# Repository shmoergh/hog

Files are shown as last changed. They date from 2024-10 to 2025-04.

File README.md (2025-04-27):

# Hog

Fully analog two-voice monophonic synth for live performances.

hog-4

Details and user guide: [shmoergh.com](https://shmoergh.com/)

Latest revision: rev #3.

## Build

The HOG is a very fun but equally advanced electronics project. It's fully open source and we've put together a build guide for the brave ones who decide to build one. Let us know if you have questions and definitely share some pics of your builds (follow [Shmøergh on Instagram](https://www.instagram.com/shmoergh/)).

[Open build guide &rarr;](https://www.shmoergh.com/guides/hog-build-guide)

## BOMs

The HOG consists of 5 separate boards which you can find in the `boards` folder. Each board has it's own gerber files for JLCPCB PCB and Mouser BOMs in the board's `production` folders. The Core and Filter boards have SMD components too for which you can find JLCPCB assembly files (BOM and position) in the `production/jlcpcb` folder.

## Cloning

The MIDI2CV module uses [`pico-lib`](https://github.com/peterzimon/pico-lib) submodule. Make sure you clone
the repo like with its submodules:

```
git clone --recurse-submodules git@github.com:shmoergh/hog.git
```

## License

Shmoergh Hog © 2024

Hardware is licensed under [CC BY-NC 4.0](https://creativecommons.org/licenses/by-nc/4.0/)

Software is licensed under [MIT](https://opensource.org/license/mit).

Font used on PCBs: https://departuremono.com

Simulations made in [CircuitJS](https://www.falstad.com/circuit/circuitjs.html)

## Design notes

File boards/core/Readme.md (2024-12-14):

## Core board

Circuit for all core modules of HOG:

- 2x VCO
- 2x Waveshapers
- VCA
- ADSR
- 2x LFO
- Sub source
- Noise source
- Output

### Versions

**Experimental** — Some parts of the circuit contains multiple solutions, options that can be selected to build. In this version there are multiple ways to build thermal compensation for the VCOs depending on component availability (NTC based, PTS100 based); it contains a precision +/-5V circuit with output connectors that can be used on the UI board if necessary; and misc. options.

**Stable** — This is the opinionated, tested and recommended version of the core board. Compared to the experimental board:

- This board uses PTS100 for thermal compensation
- It is designed for SMD manufacturing. Note that some parts are not available at JLCPCB. We kept these THT whereever it's possible for easy build.
- +/-5V precision output is removed. Instead +/-12V resistor divider is used where needed, as approximate values were fine on the Core board.

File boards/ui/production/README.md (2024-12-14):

# Production instructions

This folder contains all the production files and a complete parts list necessary for manufacturing this board. The board contains only through-hole components. The PCB files are optimized for ordering from JLCPCB, while the through-hole components are configured for ordering from Mouser and Aliexpress.

## PCB

Upload the file `./jlcpcb/ui.zip` on [jlcpcb.com](https://www.jlcpcb.com) to order the PCB.

## Through hole components

To make ordering through hole components easy we've prepared a CSV file to generate a BOM on [mouser.com](https://www.mouser.com). Here's what you need to do:

1. Go to [https://www.mouser.com](https://www.mouser.com) and log in with your account
2. Open [BOMs](https://hu.mouser.com/OrderHistory/Boms) from the account menu
3. Click on Create New BOM
4. Upload the `./mouser/ui-mouser-bom.csv` file from this directory
5. Make sure you map the `Quantity 1` and `Mouser Product Number` columns correctly
6. Create the BOM

You can order all necessary parts at once. If a part is not available you need to find replacement components, or if you want another vendor (like Digikey) then you'll need to hunt all parts yourself.

### Switches

The switches can be ordered from Aliexpress. Check out the bom file `./aliexpress/ui-alie-bom.csv` for the links. Note that these shops are quite hectic in terms of part availability. If you can't find the switches, try searching for the part number (they're in the BOM file) in Google, Google Images, Amazon or you can even try "ON-ON toggle", "ON-ON-ON toggle" in the Chinese websites.

## Disclaimer

We are not responsible for any errors in the PCB design or the parts list. All responsibility for ordering PCBs, components, and assembly services rests solely with you.

## More important disclaimer

Have fun!

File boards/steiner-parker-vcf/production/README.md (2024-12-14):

# Production instructions

This folder contains all the production files and a complete parts list necessary for manufacturing this board. The board includes both SMD and through-hole components. The PCB and SMD production files are optimized for ordering from JLCPCB, while the through-hole components are configured for ordering from Mouser.

## PCB

Upload the file `./jlcpcb/steiner-parker-vcf.zip` on [jlcpcb.com](https://www.jlcpcb.com) to order the PCB.

## SMD assembly

On JLCPCB, select the "PCB Assembly" option. Make sure you check:

- PCBA Type: Economic
- Assembly Side: Top Side
- PCBA Qty (up to you)
- Tooling Holes: Added by Customer
- Confirm Parts Placement: Yes
- Parts Selection: By Customer

Then hit Next.

Use the `./jlcpcb/bom.csv` (BOM) and `./jlcpcb/positions.csv` (CPL — position) files respectively to order SMD assembly by JLCPCB.

> Note: the BOM file contains _all_ parts (including through holes too), so you _will_ get a warning after uploading it. You can ignore this warning and continue with ordering.

CleanShot 2024-12-14 at 11 21 11@2x

‼️ **Make sure you triplecheck the rotation of each SMD component with a dedicated pin order!**

CleanShot 2024-12-14 at 11 21 53@2x

## Through hole assembly

Well you guessed it: you'll need to solder all THT components yourself. It's fun, trust me, just make sure you don't smell the smoke from your soldering iron.

To make ordering through hole components easy we've prepared a CSV file to generate a BOM on [mouser.com](https://www.mouser.com). Here's what you need to do:

1. Go to [https://www.mouser.com](https://www.mouser.com) and log in with your account
2. Open [BOMs](https://hu.mouser.com/OrderHistory/Boms) from the account menu
3. Click on Create New BOM
4. Upload the `./mouser/steiner-parker-vcf-mouser-bom.csv` file from this directory
5. Make sure you map the `Quantity 1` and `Mouser Product Number` columns correctly
6. Create the BOM

You can order all necessary parts at once. If a part is not available you need to find replacement components, or if you want another vendor (like Digikey) then you'll need to hunt all parts yourself.

## Full BOM

The `./steiner-parker-vcf-full-bom.csv` file contains all the parts including SMD and through hole if anyone would need it.

## Disclaimer

We are not responsible for any errors in the PCB design or the parts list. All responsibility for ordering PCBs, components, and assembly services rests solely with you.

## More important disclaimer

Have fun!

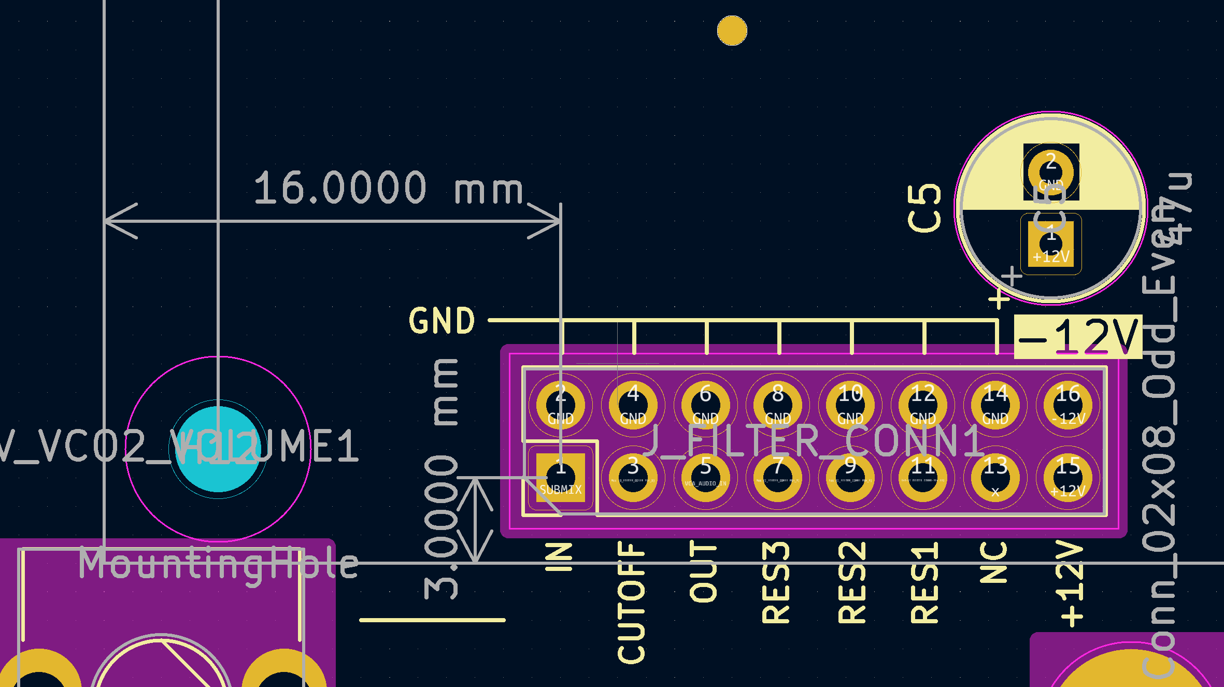
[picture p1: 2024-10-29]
boards/steiner-parker-vcf/ui-board-connection.png

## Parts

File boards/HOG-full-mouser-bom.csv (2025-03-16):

Board | Reference | Value | Footprint | Quantity | Mouser Part No | Part URL | Vendor
Core | C241 | 10u | Capacitor_THT:CP_Radial_D6.3mm_P2.50mm | 1 | 598-106RSS050M | https://mou.sr/3VxA0hV | Mouser
Core | C248 | 1u (foil or electrolite) | Capacitor_THT:C_Rect_L7.2mm_W5.5mm_P5.00mm_FKS2_FKP2_MKS2_MKP2 | 1 | 80-R82EC4100Z370K | https://mou.sr/3ZROEn2 | Mouser
Core | C251,C255 | 22n-47n (foil) | Capacitor_THT:C_Rect_L7.0mm_W2.5mm_P5.00mm | 2 | 80-R82EC1330AA50K | https://mou.sr/3BhmOHr | Mouser
Core | J201,J202,J203,J204 | Conn_02x08_Counter_Clockwise | Connector_PinHeader_2.54mm:PinHeader_2x08_P2.54mm_Vertical | 4 | 737-RS2-16-G | https://mou.sr/3OWyRwS | Mouser
Core | J214 | Conn_02x04_Counter_Clockwise | Connector_PinHeader_2.54mm:PinHeader_2x04_P2.54mm_Vertical | 1 | 737-RS2-08-G | https://mou.sr/41qYCwK | Mouser
Core | J_POWER201 | Conn_02x05_Odd_Even | Connector_PinHeader_2.54mm:PinHeader_2x05_P2.54mm_Vertical | 1 | 737-RS2-10-G | https://mou.sr/3ZuUKrQ | Mouser
Core | Q201,Q204 | 2N3906 | Package_TO_SOT_THT:TO-92L_Inline_Wide | 2 | 512-2N3906BU | https://mou.sr/3ZrOXn8 | Mouser
Core | Q203,Q206 | MMBFJ111 | PCM_Package_TO_SOT_SMD_AKL:SOT-23_Handsoldering | 2 | 512-MMBFJ111 | https://mou.sr/3Us0WP4 | Mouser
Core | Q208,Q209,Q210 | BC548C | Package_TO_SOT_THT:TO-92L_Inline_Wide | 3 | 637-BC548C | https://mou.sr/4fhkHkJ | Mouser
Core | R203,R218 | 91k | Shmoergh_Custom_Footprints:R_Axial_DIN0207_L6.3mm_D2.5mm_P7.62mm_Horizontal | 2 | 603-MFR50SFTE52-91K | https://mou.sr/3Vwa9XS | Mouser
Core | R204,R219 | 6.2k (50ppm) | Shmoergh_Custom_Footprints:R_Axial_DIN0207_L6.3mm_D2.5mm_P7.62mm_Horizontal | 2 | 603-MFR50SFTE52-6K2 | https://mou.sr/3OL65PP | Mouser
Core | R206,R221 | 4R22 (50ppm) | Shmoergh_Custom_Footprints:R_Axial_DIN0207_L6.3mm_D2.5mm_P7.62mm_Horizontal | 2 | 603-MFR50SFTE52-4R22 | https://mou.sr/49tYeQ0 | Mouser
Core | R268 | 470 | Shmoergh_Custom_Footprints:R_Axial_DIN0207_L6.3mm_D2.5mm_P7.62mm_Horizontal | 1 | 603-MFR-25FBF52-470R | https://mou.sr/3FKKllB | Mouser
Core | RV201,RV202,RV203,RV204,RV205,RV_HEADPHONE_LIM201 | 100k | Potentiometer_THT:Potentiometer_ACP_CA6-H2,5_Horizontal | 6 | 531-PT6KH104A1010PM | https://mou.sr/49zQlIS | Mouser
Core | RV_ADSR_MAX_VOLTAGE201,RV_TRI_BIAS201,RV_TRI_BIAS202 | 100k | Potentiometer_THT:Potentiometer_Bourns_3006P_Horizontal | 3 | 652-3006P-1-104-LF | https://mou.sr/4ff5W1E | Mouser
Core | RV_LINE_OUT_LVL201 | 10k | Potentiometer_THT:Potentiometer_ACP_CA6-H2,5_Horizontal | 1 | 531-PT6KH-10K | https://mou.sr/4gcYhlU | Mouser
Core | RV_SAW_BIAS201,RV_SAW_BIAS202 | 10k | Potentiometer_THT:Potentiometer_Bourns_3006P_Horizontal | 2 | 652-3006P-1-103-LF | https://mou.sr/41xh2vW | Mouser
Core | R_WIDTH201,R_WIDTH202 | 20k | Potentiometer_THT:Potentiometer_Bourns_3006P_Horizontal | 2 | 652-3006P-7-203-LF | https://mou.sr/41re1x3 | Mouser
Core | TH201,TH202 | PTS120601B100RP100 | Resistor_SMD:R_1206_3216Metric_Pad1.30x1.75mm_HandSolder | 2 | 594-PTS120601B100RP | https://mou.sr/4g7SsGi | Mouser
Core | U212 | 4002 | Package_DIP:DIP-14_W7.62mm | 1 | 595-CD4002BE | https://mou.sr/3JJTry1 | Mouser
MIDI2CV | C1,C5,C6,C10 | 22p | -- mixed values -- | 4 | 594-K220J15C0GF53L2 | https://mou.sr/3ZTXYXB | Mouser
MIDI2CV | C2 | 330n | Capacitor_THT:C_Disc_D3.0mm_W2.0mm_P2.50mm | 1 | 810-FA14X7R1H334KNU6 | https://mou.sr/4gDlMo9 | Mouser
MIDI2CV | C3,C4,C11 | 100n | Capacitor_THT:C_Disc_D3.0mm_W2.0mm_P2.50mm | 3 | 594-K103K15X7RF5TK2 | https://mou.sr/3VFZIRH | Mouser
MIDI2CV | C7 | 10u | Capacitor_THT:CP_Radial_D6.3mm_P2.50mm | 1 | 80-ESS106M035AC2EA | https://mou.sr/49DyMaU | Mouser
MIDI2CV | C8,C9 | 1u | Capacitor_THT:CP_Radial_D6.3mm_P2.50mm | 2 | 140-SG1R0M1H0407P | https://mou.sr/41BqE8O | Mouser
MIDI2CV | D1 | 1N4001 | Diode_THT:D_DO-41_SOD81_P10.16mm_Horizontal | 1 | 637-1N4001 | https://mou.sr/3DfEJyK | Mouser
MIDI2CV | D2 | 1N4148 | Diode_THT:D_DO-35_SOD27_P7.62mm_Horizontal | 1 | 512-1N4148 | https://mou.sr/3ZP7Wt3 | Mouser
MIDI2CV | JP1 | Jumper_2_Open | Connector_PinHeader_2.54mm:PinHeader_1x02_P2.54mm_Horizontal | 1 | 737-PH1RB-02-UA | https://mou.sr/3D93YT9 | Mouser
MIDI2CV | J_IN1 | Conn_01x06 | Connector_PinHeader_2.54mm:PinHeader_1x06_P2.54mm_Vertical | 1 | 737-RS1-06-G | https://mou.sr/3BuZUME | Mouser
MIDI2CV | J_OUT1,J_SWD_IO1 | Conn_01x04 | -- mixed values -- | 2 | 737-RS1-04-G | https://mou.sr/4gDjs0p | Mouser
MIDI2CV | J_SWCLKDIO1 | Conn_01x02 | Connector_PinHeader_2.54mm:PinHeader_1x02_P2.54mm_Horizontal | 1 | 737-PH1RB-02-UA | https://mou.sr/3D93YT9 | Mouser
MIDI2CV | Q_GATE_LED1 | 2N3904 | Package_TO_SOT_THT:TO-92_Inline_Wide | 1 | 637-2N3904 | https://mou.sr/4febysZ | Mouser
MIDI2CV | R1,R3 | 220 | Shmoergh_Custom_Footprints:R_Axial_DIN0207_L6.3mm_D2.5mm_P7.62mm_Horizontal | 2 | 603-MFR-25FTF52-220R | https://mou.sr/41wmEVF | Mouser
MIDI2CV | R2 | 4.7k | Shmoergh_Custom_Footprints:R_Axial_DIN0207_L6.3mm_D2.5mm_P7.62mm_Horizontal | 1 | 603-MFR-25FBF52-4K7 | https://mou.sr/4i8N07f | Mouser
MIDI2CV | R4,R12 | 47k | Shmoergh_Custom_Footprints:R_Axial_DIN0207_L6.3mm_D2.5mm_P7.62mm_Horizontal | 2 | 603-MFR-25FBF52-47K | https://mou.sr/3XWs8rz | Mouser
MIDI2CV | R5,R17 | 100k | Shmoergh_Custom_Footprints:R_Axial_DIN0207_L6.3mm_D2.5mm_P7.62mm_Horizontal | 2 | 603-MFR-25FRF52100K | https://mou.sr/4hEwI4G | Mouser
MIDI2CV | R6,R13 | 68k | Shmoergh_Custom_Footprints:R_Axial_DIN0207_L6.3mm_D2.5mm_P7.62mm_Horizontal | 2 | 603-MFR-25FBF52-68K | https://mou.sr/4gyTECt | Mouser
MIDI2CV | R7,R18 | 51k | Shmoergh_Custom_Footprints:R_Axial_DIN0207_L6.3mm_D2.5mm_P7.62mm_Horizontal | 2 | 603-MFR-25FBF52-51K | https://mou.sr/43NIOFo | Mouser
MIDI2CV | R8 | 10k | Shmoergh_Custom_Footprints:R_Axial_DIN0207_L6.3mm_D2.5mm_P7.62mm_Horizontal | 1 | 603-MFR25SFRF52-10K | https://mou.sr/3XU3MyE | Mouser
MIDI2CV | R9,R10,R14,R15,R16,R19 | 1k | Shmoergh_Custom_Footprints:R_Axial_DIN0207_L6.3mm_D2.5mm_P7.62mm_Horizontal | 6 | 603-MFR-25FBF52-1K | https://mou.sr/43MmrAb | Mouser
MIDI2CV | R11 | 470 | Shmoergh_Custom_Footprints:R_Axial_DIN0207_L6.3mm_D2.5mm_P7.62mm_Horizontal | 1 | 603-MFR-25FBF52-470R | https://mou.sr/3XTF2Xk | Mouser
MIDI2CV | U1 | LM7805_TO220 | Package_TO_SOT_THT:TO-220-3_Horizontal_TabDown | 1 | 926-LM7805CT/NOPB | https://mou.sr/4gwivXu | Mouser
MIDI2CV | U2 | 6N138 | Package_DIP:DIP-8_W7.62mm_LongPads | 1 | 859-6N138M | https://mou.sr/3VDrRsD | Mouser
MIDI2CV | U3,U6 | LM358 | Package_DIP:DIP-8_W7.62mm_LongPads | 2 | 595-LM358P | https://mou.sr/4izjQPc | Mouser
MIDI2CV | U4 | MCP4822 | Package_DIP:DIP-8_W7.62mm_LongPads | 1 | 579-MCP4822-E/P | https://mou.sr/4gecDm5 | Mouser
MIDI2CV | U5 | Pico | MCU_RaspberryPi_and_Boards:RPi_Pico_SMD_TH | 1 | 358-SC0915 | https://mou.sr/49BoTdS | Mouser
PSU | IC1 | NSD10-12D12 | NSD1012D5 | 1 | 709-NSD10-12D12 | https://mou.sr/3ZpECrS | Mouser
PSU | J1 | Conn_02x04_Odd_Even | Connector_PinSocket_2.54mm:PinSocket_2x04_P2.54mm_Vertical | 1 | 737-RS2-08-G | https://mou.sr/41qYCwK | Mouser
PSU | J2 | Conn_02x05_Odd_Even | Connector_PinSocket_2.54mm:PinSocket_2x05_P2.54mm_Vertical | 1 | 737-RS2-10-G | https://mou.sr/3ZuUKrQ | Mouser
Filter | C9,C11,C13 | 1n (Foil) | Capacitor_THT:C_Rect_L7.0mm_W2.5mm_P5.00mm | 3 | 80-R82EC1100SH50J | https://mou.sr/3ZRLX4F | Mouser
Filter | C17 | 470n (foil) | Capacitor_THT:C_Rect_L7.0mm_W3.5mm_P5.00mm | 1 | 80-R82EC1470DQ50K | https://mou.sr/4g5F5Xb | Mouser
Filter | C18 | 1u (Foil) | Capacitor_THT:C_Rect_L7.0mm_W4.5mm_P5.00mm | 1 | 80-R82EC4100Z370K | https://mou.sr/3ZROEn2 | Mouser
Filter | J1 | Eurorack Power | Connector_PinHeader_2.54mm:PinHeader_2x05_P2.54mm_Vertical | 1 | 737-RS2-10-G | https://mou.sr/3ZTZokP | Mouser
Filter | J3 | Conn_02x08_Odd_Even | Connector_PinHeader_2.54mm:PinHeader_2x08_P2.54mm_Vertical | 1 | 737-RS2-16-G | https://mou.sr/3DcrsXN | Mouser
Filter | JP_INT_EXT1 | Internal/External CV | Connector_PinSocket_2.54mm:PinSocket_1x03_P2.54mm_Vertical | 1 | 737-PH1-20-UA | https://mou.sr/4gqTRHQ | Mouser
Filter | Q1 | BC547B | Package_TO_SOT_THT:TO-92_Inline_Wide | 1 | 637-BC547B | https://mou.sr/49DWqUL | Mouser
Filter | R3 | 6.8k | Shmoergh_Custom_Footprints:R_Axial_DIN0207_L6.3mm_D2.5mm_P7.62mm_Horizontal | 1 | 603-CFR-25JB-52-6K8 | https://mou.sr/3FwCIPM | Mouser
Filter | R4 | 3.3k | Shmoergh_Custom_Footprints:R_Axial_DIN0207_L6.3mm_D2.5mm_P7.62mm_Horizontal | 1 | 603-CFR-25JB-52-3K3 | https://mou.sr/4bzT0TY | Mouser
Filter | RV_BALANCE1 | 1k | Potentiometer_THT:Potentiometer_ACP_CA6-H2,5_Horizontal | 1 | 531-PT6KH-1K | https://mou.sr/3DgNY1x | Mouser
Filter | RV_BIAS1 | 10k | Potentiometer_THT:Potentiometer_ACP_CA6-H2,5_Horizontal | 1 | 531-PT6KH-10K | https://mou.sr/49CavSt | Mouser
Filter | RV_MAX_RESO1 | 100k | Potentiometer_THT:Potentiometer_ACP_CA6-H2,5_Horizontal | 1 | 531-PT6KH104A1010PM | https://mou.sr/3OVlmh2 | Mouser
UI | C1,C2 | 100u | Capacitor_THT:CP_Radial_D6.3mm_P2.50mm | 2 | 80-ESS107M025AE2AA | https://mou.sr/3ZTs1yq | Mouser
UI | C3 | 1n | Capacitor_THT:C_Disc_D3.0mm_W2.0mm_P2.50mm | 1 | 594-K102M15X7RF53L2 | https://mou.sr/3OTl4qX | Mouser
UI | C4 | 10n | Capacitor_THT:C_Disc_D3.0mm_W2.0mm_P2.50mm | 1 | 594-K103K15X7RF5TK2 | https://mou.sr/49C1dG8 | Mouser
UI | C5 | 47u | Capacitor_THT:CP_Radial_D6.3mm_P2.50mm | 1 | 667-ECE-A1VKS470I | https://mou.sr/4iyQHDI | Mouser
UI | C7,C8,C9,C10 | 100n | Capacitor_THT:C_Disc_D3.0mm_W2.0mm_P2.50mm | 4 | 594-K103K15X7RF5TK2 | https://mou.sr/3VFZIRH | Mouser
UI | C12 | 470n | Capacitor_THT:C_Disc_D3.0mm_W2.0mm_P2.50mm | 1 | 80-C315C474K5R | https://mou.sr/4ggiw21 | Mouser
UI | D1,D3,D_ON_OFF1 | LED Blue | LED_THT:LED_D5.0mm | 3 | 859-LTL-1CHG | https://mou.sr/3OXMWKk | Mouser
UI | D2 | 8.2V | Diode_THT:D_DO-41_SOD81_P7.62mm_Horizontal | 1 | 625-BZX85C8V2 | https://mou.sr/3DeplTn | Mouser
UI | J1,J2,J3,J4 | Conn_02x08_Counter_Clockwise | Connector_PinHeader_2.54mm:PinHeader_2x08_P2.54mm_Vertical | 4 | 649-1012938191601BLF | https://mou.sr/3ZS3vh3 | Mouser
UI | J5 | Conn_02x04_Counter_Clockwise | Connector_PinHeader_2.54mm:PinHeader_2x04_P2.54mm_Vertical | 1 | 737-PH2-08-UA | https://mou.sr/4gxLnib | Mouser
UI | J6 | Barrel_Jack_Switch | Connector_BarrelJack:BarrelJack_Wuerth_6941xx301002 | 1 | 710-694106301002 | https://mou.sr/4a9ckVQ | Mouser
UI | J8 | Conn_01x06 | Connector_PinHeader_2.54mm:PinHeader_1x06_P2.54mm_Vertical | 1 | 737-PH1-20-UA | https://mou.sr/4gqTRHQ | Mouser
UI | J9 | Conn_02x04_Odd_Even | Connector_PinHeader_2.54mm:PinHeader_2x04_P2.54mm_Vertical | 1 | 737-PH2-08-UA | https://mou.sr/4gxLnib | Mouser
UI | J_EXT_CUTOFF1,J_GATE1,J_HEADPHONES1,J_MIDI_IN1,J_PITCH1,J_VCO2_PITCH1 | SJ1-3554NG | Shmoergh_Custom_Footprints:CUI_SJ1-3554NG | 6 | 490-SJ1-3554NG | https://mou.sr/3Qs21VB | Mouser
UI | J_FILTER_CONN1 | Conn_02x08_Odd_Even | Connector_PinHeader_2.54mm:PinHeader_2x08_P2.54mm_Vertical | 1 | 649-1012938191601BLF | https://mou.sr/3ZS3vh3 | Mouser
UI | J_MAIN_POWER1,J_POWER1 | Conn_02x05_Odd_Even | Connector_PinHeader_2.54mm:PinHeader_2x05_P2.54mm_Vertical | 2 | 737-PH2-10-UA | https://mou.sr/3D13TAT | Mouser
UI | Q1,Q2 | 2N3904 | Package_TO_SOT_THT:TO-92L_Inline_Wide | 2 | 637-2N3904 | https://mou.sr/4febysZ | Mouser
UI | R1 | 1k | Shmoergh_Custom_Footprints:R_Axial_DIN0207_L6.3mm_D2.5mm_P7.62mm_Horizontal | 1 | 603-MFR-25FBF52-1K | https://mou.sr/43MmrAb | Mouser
UI | R2,R44,R45 | 200k | Shmoergh_Custom_Footprints:R_Axial_DIN0207_L6.3mm_D2.5mm_P7.62mm_Horizontal | 3 | 603-MFR-25FTF52-200K | https://mou.sr/49BK9jG | Mouser
UI | R3,R4,R5,R6,R7,R14,R15,R16,R17 | 10k (0.1%) | Shmoergh_Custom_Footprints:R_Axial_DIN0207_L6.3mm_D2.5mm_P7.62mm_Horizontal | 9 | 660-MF1/4CCT52R1002B | https://mou.sr/4fj3JT3 | Mouser
UI | R8 | 150k | Shmoergh_Custom_Footprints:R_Axial_DIN0207_L6.3mm_D2.5mm_P7.62mm_Horizontal | 1 | 603-MFR-25FBF52-150K | https://mou.sr/3DLvBCw | Mouser
UI | R9,R10,R26,R30,R38,R40,R49 | 100k | Shmoergh_Custom_Footprints:R_Axial_DIN0207_L6.3mm_D2.5mm_P7.62mm_Horizontal | 7 | 603-MFR-25FRF52100K | https://mou.sr/4hEwI4G | Mouser
UI | R11,R12,R13,R19,R20,R21,R22,R25,R31,R32,R33 | 100k (1%) | Shmoergh_Custom_Footprints:R_Axial_DIN0207_L6.3mm_D2.5mm_P7.62mm_Horizontal | 11 | 603-MFR-25FRF52100K | https://mou.sr/4hEwI4G | Mouser
UI | R18,R23,R24,R39 | 82k | Shmoergh_Custom_Footprints:R_Axial_DIN0207_L6.3mm_D2.5mm_P7.62mm_Horizontal | 4 | 603-MFR-25FBF52-82K | https://mou.sr/4bFupx1 | Mouser
UI | R27,R28,R35,R36,R43,R50,R51 | 10k | Shmoergh_Custom_Footprints:R_Axial_DIN0207_L6.3mm_D2.5mm_P7.62mm_Horizontal | 7 | 603-MFR25SFRF52-10K | https://mou.sr/3XU3MyE | Mouser
UI | R29 | 330k | Shmoergh_Custom_Footprints:R_Axial_DIN0207_L6.3mm_D2.5mm_P7.62mm_Horizontal | 1 | 603-MFR-25FRF52-330K | https://mou.sr/3FzGuYE | Mouser
UI | R34 | 2k | Shmoergh_Custom_Footprints:R_Axial_DIN0207_L6.3mm_D2.5mm_P7.62mm_Horizontal | 1 | 603-MFR-25FTF52-2K | https://mou.sr/425kXjj | Mouser
UI | R37,R41 | 20k | Shmoergh_Custom_Footprints:R_Axial_DIN0207_L6.3mm_D2.5mm_P7.62mm_Horizontal | 2 | 603-MFR-25FRF5220K | https://mou.sr/4bBnUeQ | Mouser
UI | R42 | 4.7k | Shmoergh_Custom_Footprints:R_Axial_DIN0207_L6.3mm_D2.5mm_P7.62mm_Horizontal | 1 | 603-MFR-25FBF52-4K7 | https://mou.sr/4i8N07f | Mouser
UI | R46,R47 | 220 | Shmoergh_Custom_Footprints:R_Axial_DIN0207_L6.3mm_D2.5mm_P7.62mm_Horizontal | 2 | 603-MFR-25FTE52-220R | https://mou.sr/428sz4x | Mouser
UI | R48 | 47k | Shmoergh_Custom_Footprints:R_Axial_DIN0207_L6.3mm_D2.5mm_P7.62mm_Horizontal | 1 | 603-MFR-25FTE52-47K | https://mou.sr/4iUy6Bg | Mouser
UI | RV1,RV2 | 50k prec. | Potentiometer_THT:Potentiometer_Bourns_3006P_Horizontal | 2 | 652-3006P-1-503-LF | https://mou.sr/3ZEVzhM | Mouser
UI | RV_ATTACK_LONG1,RV_DECAY_SHORT1,RV_DIRTY_AMP1,RV_EXT_CUTOFF_GAIN1,RV_GLIDE_AMNT1,RV_NARROW_WIDTH1,RV_PLAYGROUND_HALF1,RV_RELEASE_MIN1,RV_RELEASE_SHORT1,RV_SUSTAIN_LVL1,RV_SYNC_VIBRATO_DAMP1,RV_TRACKING_LVL1,RV_VCA_PLYGND_BIAS1 | 100k | Potentiometer_THT:Potentiometer_Runtron_RM-065_Vertical | 13 | 652-3306F-1-104 | https://mou.sr/3OVBYFf | Mouser
UI | RV_ATTACK_SHORT1 | 10k | Potentiometer_THT:Potentiometer_Runtron_RM-065_Vertical | 1 | 652-3306F-1-103 | https://mou.sr/41GreC6 | Mouser
UI | RV_CUTOFF1,RV_VCO2_TUNER1 | 100k | Shmoergh_Custom_Footprints:Potentiometer_Bourns_Single-PTV09A | 2 | 652-PTV09A4025FB104 | https://mou.sr/3Us6dpJ | Mouser
UI | RV_FINE_TUNE1 | 10k | Shmoergh_Custom_Footprints:Potentiometer_Bourns_PTD901-2015_Single_Horizontal | 1 | PTD901-1015K-B103 | https://mou.sr/4aB7CRn | Mouser
UI | RV_LFO1_AMOUNT1,RV_LFO1_SPEED1,RV_LFO2_AMOUNT1,RV_LFO2_SPEED1,RV_NOISE_VOLUME1,RV_VCO2_VOLUME1 | A100k | Shmoergh_Custom_Footprints:Potentiometer_Bourns_Single-PTV09A | 6 | 652-PTV09A-4025UA104 | https://mou.sr/44vDepN | Mouser
UI | RV_MAIN_VCO_5V1 | 10k | Potentiometer_THT:Potentiometer_Bourns_3006P_Horizontal | 1 | 652-3006P-1-103-LF | https://mou.sr/41xh2vW | Mouser
UI | RV_PWM_LEVEL1,RV_SUSTAIN_MAX1 | 200k | Potentiometer_THT:Potentiometer_Runtron_RM-065_Vertical | 2 | 652-3306F-1-204 | https://mou.sr/3P2IKcd | Mouser
UI | RV_RESO_DIRTY1 | 50k | Shmoergh_Custom_Footprints:Potentiometer_Bourns_Dual-PTV112-4 | 1 | 652-PTV112-4425AB503 | https://mou.sr/3UKAAJn | Mouser
UI | RV_RINGTIME1 | 500k | Shmoergh_Custom_Footprints:Potentiometer_Bourns_Dual-PTV112-4 | 1 | 652-PTV1124420AA504 | https://mou.sr/47iqFh2 | Mouser
UI | RV_VOLUME1 | A10k | Shmoergh_Custom_Footprints:Potentiometer_Bourns_Single-PTV09A | 1 | 652-PTV09A4025FA103 | https://mou.sr/4bCOV0e | Mouser
UI | S1 | PB400EEQR1BLK | Shmoergh_Custom_Footprints:SW_PB400EEQR1BLK | 1 | 612-PB400EEQR1BLK | https://mou.sr/3TDv9tV | Mouser
UI | SW_OCTAVE1,SW_WAVESHAPE1 | SW_Rotary2x5 | Shmoergh_Custom_Footprints:SW_SR2512F-2x5-rotary | 2 | 105-SR2512F-25NS | https://mou.sr/49HHdSv | Mouser
UI | SW_PLAYGROUND1 | SW_Rotary3x4 | Shmoergh_Custom_Footprints:SW_SR2512F-3x4-rotary | 1 | 105-SR2512F-34NS | https://mou.sr/3wb0uwA | Mouser
UI | U1,U2 | TL072 | PCM_Package_DIP_AKL:DIP-8_W7.62mm_Socket_LongPads | 2 | 595-TL072IP | https://mou.sr/4g5XjI5 | Mouser
UI | U_5VREF1 | LM336Z5 | Package_TO_SOT_THT:TO-92L_Inline_Wide | 1 | 926-LM336Z-50/NOPB | https://mou.sr/3y3TEcP | Mouser
UI | U_ADSR_SW_IC1 | CD4053B | Package_DIP:DIP-16_W7.62mm | 1 | 595-CD4053BE | https://mou.sr/4a7avII | Mouser

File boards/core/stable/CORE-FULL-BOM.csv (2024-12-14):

Reference | Value | Datasheet | Footprint | Qty | DNP | LCSC | Part No. | Part URL | Vendor
C201,C202,C203,C204,C205,C206,C211,C212,C213,C214,C215,C216,C221,C222,C223,C224,C229,C230,C231,C232,C233,C234,C237,C238,C239,C242,C243,C244,C245,C246,C247,C249,C250,C253,C254,C257,C258,C259,C262,C263,C265,C266,C267,C268,C269,C270,C278,C279 | 100n | ~ | Capacitor_SMD:C_0603_1608Metric | 48 |  | C14663 |  |  | JLCPCB
C208,C218,C276 | 100p | ~ | Capacitor_SMD:C_0603_1608Metric | 3 |  | C14858 |  |  | JLCPCB
C210,C220 | 22p | ~ | Capacitor_SMD:C_0603_1608Metric | 2 |  | C1653 |  |  | JLCPCB
C225,C226,C227,C275 | 22uF | ~ | Capacitor_SMD:CP_Elec_6.3x5.4 | 4 |  | C2836438 |  |  | JLCPCB
C236,C272 | 33p | ~ | Capacitor_SMD:C_0603_1608Metric | 2 |  | C1663 |  |  | JLCPCB
C240 | 10n | ~ | Capacitor_SMD:C_0603_1608Metric | 1 |  | C57112 |  |  | JLCPCB
C241 | 10u | ~ | Capacitor_THT:CP_Radial_D6.3mm_P2.50mm | 1 |  |  | 598-106RSS050M | https://mou.sr/3VxA0hV | Mouser
C248 | 1u (foil or electrolite) | ~ | Capacitor_THT:C_Rect_L7.2mm_W5.5mm_P5.00mm_FKS2_FKP2_MKS2_MKP2 | 1 |  |  | 80-R82EC4100Z370K | https://mou.sr/3ZROEn2 | Mouser
C251,C255 | 22n-47n (foil) | ~ | Capacitor_THT:C_Rect_L7.0mm_W2.5mm_P5.00mm | 2 |  |  | 80-R82EC1330AA50K | https://mou.sr/3BhmOHr | Mouser
C252,C256,C280,C281 | 47u | ~ | Capacitor_SMD:CP_Elec_6.3x5.4 | 4 |  | C3344 |  |  | JLCPCB
C260,C261 | 100u | ~ | Capacitor_SMD:CP_Elec_6.3x7.7 | 2 |  | C2836437 |  |  | JLCPCB
C273,C274,C282,C283,C284,C285 | 47p | ~ | Capacitor_SMD:C_0603_1608Metric | 6 |  | C1671 |  |  | JLCPCB
C277 | 1u | ~ | Capacitor_SMD:C_0603_1608Metric_Pad1.08x0.95mm_HandSolder | 1 |  | C15849 |  |  | JLCPCB
D203,D204,D207,D212,D213,D216,D217 | 1N4148 | ~ | Diode_SMD:D_SOD-123 | 7 |  | C81598 |  |  | JLCPCB
J201,J202,J203,J204 | Conn_02x08_Counter_Clockwise | ~ | Connector_PinHeader_2.54mm:PinHeader_2x08_P2.54mm_Vertical | 4 |  |  | 737-RS2-16-G | https://mou.sr/3OWyRwS | Mouser
J214 | Conn_02x04_Counter_Clockwise | ~ | Connector_PinHeader_2.54mm:PinHeader_2x04_P2.54mm_Vertical | 1 |  |  | 737-RS2-08-G | https://mou.sr/41qYCwK | Mouser
J_POWER201 | Conn_02x05_Odd_Even | ~ | Connector_PinHeader_2.54mm:PinHeader_2x05_P2.54mm_Vertical | 1 |  |  | 737-RS2-10-G | https://mou.sr/3ZuUKrQ | Mouser
Q201,Q204 | 2N3906 | https://www.tme.eu/Document/1d69ece8147fa5a64114d103f531c790/2N3906BU.pdf | Package_TO_SOT_THT:TO-92L_Inline_Wide | 2 |  |  | 512-2N3906BU | https://mou.sr/3ZrOXn8 | Mouser
Q202,Q205 | BC847BS | https://www.tme.eu/Document/82748fbc26f250e671ae2786c3be5a04/BC847BS.115.pdf | Package_TO_SOT_SMD:SOT-363_SC-70-6_Handsoldering | 2 |  | C5380687 |  |  | JLCPCB
Q203,Q206 | MMBFJ111 | https://www.tme.eu/Document/2ab8d7a6d6d8a209f9d7deeb52763e9f/J111.pdf | PCM_Package_TO_SOT_SMD_AKL:SOT-23_Handsoldering | 2 |  |  | 512-MMBFJ111 | https://mou.sr/3Us0WP4 | Mouser
Q207 | BC847BS | https://www.tme.eu/Document/82748fbc26f250e671ae2786c3be5a04/BC847BS.115.pdf | Package_TO_SOT_SMD:SOT-363_SC-70-6 | 1 |  | C5380687 |  |  | JLCPCB
Q208,Q209,Q210 | BC548C | https://www.onsemi.com/pub/Collateral/BC550-D.pdf | Package_TO_SOT_THT:TO-92L_Inline_Wide | 3 |  |  | 637-BC548C | https://mou.sr/4fhkHkJ | Mouser
Q212,Q213,Q214 | MMBT5551 | https://datasheet.lcsc.com/lcsc/2304140030_Jiangsu-Changjing-Electronics-Technology-Co---Ltd--MMBT5551_C2145.pdf | Package_TO_SOT_SMD:SOT-23 | 3 |  | C2145 |  |  | JLCPCB
R201,R213,R216,R228,R232,R235,R237,R242,R243,R244,R246,R247,R250,R252,R253,R254,R255,R262,R263,R264,R278,R279,R280,R281,R282,R283,R284,R285,R286,R287,R301,R304,R306,R307,R308,R309,R316,R317,R318,R319,R326,R327,R328,R329,R335,R336,R337,R338,R339,R340 | 100k | ~ | Resistor_SMD:R_0603_1608Metric | 50 |  | C25803 |  |  | JLCPCB
R202,R212,R217,R227 | 150k | ~ | Resistor_SMD:R_0603_1608Metric | 4 |  | C22807 |  |  | JLCPCB
R203,R218 | 91k | ~ | Shmoergh_Custom_Footprints:R_Axial_DIN0207_L6.3mm_D2.5mm_P7.62mm_Horizontal | 2 |  |  | 603-MFR50SFTE52-91K | https://mou.sr/3Vwa9XS | Mouser
R204,R219 | 6.2k (50ppm) | ~ | Shmoergh_Custom_Footprints:R_Axial_DIN0207_L6.3mm_D2.5mm_P7.62mm_Horizontal | 2 |  |  | 603-MFR50SFTE52-6K2 | https://mou.sr/3OL65PP | Mouser
R205,R208,R220,R223,R322,R323 | 1M | ~ | Resistor_SMD:R_0603_1608Metric | 6 |  | C22935 |  |  | JLCPCB
R206,R221 | 4R22 (50ppm) | ~ | Shmoergh_Custom_Footprints:R_Axial_DIN0207_L6.3mm_D2.5mm_P7.62mm_Horizontal | 2 |  |  | 603-MFR50SFTE52-4R22 | https://mou.sr/49tYeQ0 | Mouser
R207,R209,R222,R224 | 1.5k | ~ | Resistor_SMD:R_0603_1608Metric | 4 |  | C22843 |  |  | JLCPCB
R210,R225 | 510 | ~ | Resistor_SMD:R_0603_1608Metric | 2 |  | C23193 |  |  | JLCPCB
R211,R226 | 22k | ~ | Resistor_SMD:R_0603_1608Metric | 2 |  | C31850 |  |  | JLCPCB
R214,R229 | 330k | ~ | Resistor_SMD:R_0603_1608Metric | 2 |  | C23137 |  |  | JLCPCB
R215,R230,R258,R297,R312 | 2.2k | ~ | Resistor_SMD:R_0603_1608Metric | 5 |  | C4190 |  |  | JLCPCB
R231 | 4.7k | ~ | Resistor_SMD:R_0603_1608Metric | 1 |  | C23162 |  |  | JLCPCB
R233 | 220 | ~ | Resistor_SMD:R_0603_1608Metric | 1 |  | C22962 |  |  | JLCPCB
R234,R245 | 33k | ~ | Resistor_SMD:R_0603_1608Metric | 2 |  | C4216 |  |  | JLCPCB
R236,R238,R239,R266,R288,R289,R324,R325 | 10k | ~ | Resistor_SMD:R_0603_1608Metric | 8 |  | C25804 |  |  | JLCPCB
R240,R241,R296 | 470k | ~ | Resistor_SMD:R_0603_1608Metric | 3 |  | C23178 |  |  | JLCPCB
R248,R249,R302,R303 | 15k | ~ | Resistor_SMD:R_0603_1608Metric | 4 |  | C22809 |  |  | JLCPCB
R251,R305 | 27k | ~ | Resistor_SMD:R_0603_1608Metric | 2 |  | C22967 |  |  | JLCPCB
R256,R259,R310,R313,R320 | 220k | ~ | Resistor_SMD:R_0603_1608Metric | 5 |  | C22961 |  |  | JLCPCB
R257,R267,R290,R291,R292,R293,R311,R321,R330,R331,R332,R333,R334 | 47k | ~ | Resistor_SMD:R_0603_1608Metric | 13 |  | C25819 |  |  | JLCPCB
R260,R314 | 2.2M | ~ | Resistor_SMD:R_0603_1608Metric | 2 |  | C22938 |  |  | JLCPCB
R261,R300,R315 | 240k | ~ | Resistor_SMD:R_0603_1608Metric | 3 |  | -- mixed values -- |  |  | JLCPCB
R265 | 75k | ~ | Resistor_SMD:R_0603_1608Metric | 1 |  | C23242 |  |  | JLCPCB
R268 | 470 | ~ | Shmoergh_Custom_Footprints:R_Axial_DIN0207_L6.3mm_D2.5mm_P7.62mm_Horizontal | 1 |  |  | 303-CFR0W4J0471B00 | https://mou.sr/49DiyPd | Mouser
R269,R272,R277,R294,R295 | 1k | ~ | Resistor_SMD:R_0603_1608Metric | 5 |  | C21190 |  |  | JLCPCB
R270 | 100k | ~ | Resistor_SMD:R_0603_1608Metric_Pad0.98x0.95mm_HandSolder | 1 |  | C25803 |  |  | JLCPCB
R271 | 150 | ~ | Resistor_SMD:R_0603_1608Metric | 1 |  | C22808 |  |  | JLCPCB
R273,R274 | 100 | ~ | Resistor_SMD:R_0603_1608Metric | 2 |  | C22775 |  |  | JLCPCB
R298 | 3.3M | ~ | Resistor_SMD:R_0603_1608Metric | 1 |  | C141659 |  |  | JLCPCB
RV201,RV202,RV203,RV204,RV205,RV_HEADPHONE_LIM201 | 100k | ~ | Potentiometer_THT:Potentiometer_ACP_CA6-H2,5_Horizontal | 6 |  |  | 531-PT6KH104A1010PM | https://mou.sr/49zQlIS | Mouser
RV_ADSR_MAX_VOLTAGE201,RV_TRI_BIAS201,RV_TRI_BIAS202 | 100k | ~ | Potentiometer_THT:Potentiometer_Bourns_3006P_Horizontal | 3 |  |  | 652-3006P-1-104-LF | https://mou.sr/4ff5W1E | Mouser
RV_LINE_OUT_LVL201 | 10k | ~ | Potentiometer_THT:Potentiometer_ACP_CA6-H2,5_Horizontal | 1 |  |  | 531-PT6KH-10K | https://mou.sr/4gcYhlU | Mouser
RV_SAW_BIAS201,RV_SAW_BIAS202 | 10k | ~ | Potentiometer_THT:Potentiometer_Bourns_3006P_Horizontal | 2 |  |  | 652-3006P-1-103-LF | https://mou.sr/41xh2vW | Mouser
R_WIDTH201,R_WIDTH202 | 20k | ~ | Potentiometer_THT:Potentiometer_Bourns_3006P_Horizontal | 2 |  |  | 652-3006P-7-203-LF | https://mou.sr/41re1x3 | Mouser
TH201,TH202 | PTS120601B100RP100 | ~ | Resistor_SMD:R_1206_3216Metric_Pad1.30x1.75mm_HandSolder | 2 |  |  | 594-PTS120601B100RP | https://mou.sr/4g7SsGi | Mouser
U201,U202,U204,U205,U207,U208,U209,U210,U211,U214,U217,U218,U219,U220,U221,U222,U223,U225,U226,U227 | TL072 | http://www.ti.com/lit/ds/symlink/tl071.pdf | Package_SO:SOIC-8_3.9x4.9mm_P1.27mm | 20 |  | C6961 |  |  | JLCPCB
U203,U206 | LM311 | https://www.st.com/resource/en/datasheet/lm311.pdf | Package_SO:SOIC-8_3.9x4.9mm_P1.27mm | 2 |  | C12597 |  |  | JLCPCB
U212 | 4002 | http://www.intersil.com/content/dam/Intersil/documents/cd40/cd4000bms-01bms-02bms-25bms.pdf | Package_DIP:DIP-14_W7.62mm | 1 |  |  | 595-CD4002BE | https://mou.sr/3JJTry1 | Mouser
U213 | LM358 | http://www.ti.com/lit/ds/symlink/lm2904-n.pdf | Package_SO:SOIC-8_3.9x4.9mm_P1.27mm | 1 |  | C7950 |  |  | JLCPCB
U215 | CD4053B | http://www.ti.com/lit/ds/symlink/cd4052b.pdf | Package_SO:SOIC-16_3.9x9.9mm_P1.27mm | 1 |  | C6742 |  |  | JLCPCB
U216 | NE5532 | http://www.ti.com/lit/ds/symlink/ne5532.pdf | Package_SO:SOIC-8_3.9x4.9mm_P1.27mm | 1 |  | C7426 |  |  | JLCPCB
U228 | CD4040BM96 | http://www.intersil.com/content/dam/Intersil/documents/cd40/cd4020bms-24bms-40bms.pdf | Package_SO:SOIC-16_3.9x9.9mm_P1.27mm | 1 |  | C353974 |  |  | JLCPCB

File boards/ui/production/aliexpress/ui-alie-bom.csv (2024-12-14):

Reference | Value | Datasheet | Footprint | Qty | DNP | Part No. | Part URL | Vendor
SW_AUTO_WAH_AB1,SW_GATE_ADSR1,SW_NOISE_SUB1,SW_PLAYGROUND_LVL1,SW_VCO2_OCT_DIR1,SW_VCO2_WAVE1,SW_VIBRATO_AB1 | SW_DP3T | ~ | Shmoergh_Custom_Footprints:DP3T Korg Style Switch | 7 |  | TS23-E02 | https://www.aliexpress.com/item/32958319752.html | Daier
SW_GLIDE1,SW_HOLD1,SW_RING1,SW_SOFT1,SW_TRACK1,SW_VCO2_OCT_AMNT1,SW_VCO2_ON1 | SW_DPDT_x2 | ~ | Shmoergh_Custom_Footprints:DPDT Korg Style Switch | 7 |  | TS-22E01AT15 | https://www.aliexpress.com/item/32955400123.html | Daier

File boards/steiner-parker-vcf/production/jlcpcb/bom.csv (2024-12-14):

Designator | Footprint | Quantity | Value | LCSC Part #
C1, C2, C22, C23 | CP_Elec_6.3x7.7 | 4 | 100u | C2836437
C10 | CP_Elec_4x5.4 | 1 | 2.2u | C43242
C11, C13, C9 | C_Rect_L7.0mm_W2.5mm_P5.00mm | 3 | 1n (Foil)
C14, C16, C20, C21, C3, C4, C6, C7 | 0603 | 8 | 100n | C14663
C17 | C_Rect_L7.0mm_W3.5mm_P5.00mm | 1 | 470n (foil)
C18 | C_Rect_L7.0mm_W4.5mm_P5.00mm | 1 | 1u (Foil)
C19 | CP_Elec_4x5.4 | 1 | 10u | C3343
C8 | 0603 | 1 | 10n | C57112
D1, D10, D2, D3, D4, D5, D6, D7, D8, D9 | D_SOD-123 | 10 | 1N4148 | C81598
J1 | PinHeader_2x05_P2.54mm_Vertical | 1 | Eurorack Power
J3 | PinHeader_2x08_P2.54mm_Vertical | 1 | Conn_02x08_Odd_Even
JP_INT_EXT1 | PinSocket_1x03_P2.54mm_Vertical | 1 | Internal/External CV
Q1 | TO-92_Inline_Wide | 1 | BC547B
R10 | 0603 | 1 | 56k | C23206
R11, R32, R5 | 0603 | 3 | 10k | C25804
R12, R28 | 0603 | 2 | 47k | C25819
R13 | 0603 | 1 | 200k | C25811
R14 | 0603 | 1 | 180k | C3016400
R15 | 0603 | 1 | 2.7k | C13167
R16, R24 | 0603 | 2 | 1.5k (1%) | C22843
R17 | 0603 | 1 | 2.2k | C4190
R18 | 0603 | 1 | 100 | C22775
R19 | 0603 | 1 | 390 | C23151
R20, R21, R25, R35 | 0603 | 4 | 1k | C21190
R22 | 0603 | 1 | 3.9k | C23018
R23 | 0603 | 1 | 200 | C8218
R26, R29 | 0603 | 2 | 1M | C22935
R27 | 0603 | 1 | 22k | C31850
R3 | R_Axial_DIN0207_L6.3mm_D2.5mm_P7.62mm_Horizontal | 1 | 6.8k
R31, R9 | 0603 | 2 | 220k | C22961
R33, R34, R6 | 0603 | 3 | 100k | C25803
R4 | R_Axial_DIN0207_L6.3mm_D2.5mm_P7.62mm_Horizontal | 1 | 3.3k
RV_BALANCE1 | Potentiometer_ACP_CA6-H2,5_Horizontal | 1 | 1k
RV_BIAS1 | Potentiometer_ACP_CA6-H2,5_Horizontal | 1 | 10k
RV_MAX_RESO1 | Potentiometer_ACP_CA6-H2,5_Horizontal | 1 | 100k
U1, U2, U3 | SOIC-8_3.9x4.9mm_P1.27mm | 3 | TL072 | C6961

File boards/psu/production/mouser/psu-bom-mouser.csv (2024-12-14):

Reference | Value | Footprint | Quantity 1 | DNP | Vendor | Mouser Part Number | Part URL
IC1 | NSD10-12D12 | NSD1012D5 | 1 |  | Mouser | 709-NSD10-12D12 | https://mou.sr/3ZpECrS
J1 | Conn_02x04_Odd_Even | Connector_PinSocket_2.54mm:PinSocket_2x04_P2.54mm_Vertical | 1 |  | Mouser | 737-RS2-08-G | https://mou.sr/41qYCwK
J2 | Conn_02x05_Odd_Even | Connector_PinSocket_2.54mm:PinSocket_2x05_P2.54mm_Vertical | 1 |  | Mouser | 737-RS2-10-G | https://mou.sr/3ZuUKrQ

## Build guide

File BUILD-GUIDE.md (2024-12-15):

# Build guide

[Open build guide &rarr;](https://www.shmoergh.com/hog-build-guide)

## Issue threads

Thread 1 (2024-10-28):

Build guide request

machinehistories, 2024-10-28:
This is a terrific looking device and I'd be interested to try and build one. I see the guide on the synth features but do you have a build guide. Is there one already available and if not is there one in the works. Keep up the good work. Thanks

peterzimon, 2024-10-30:
@machinehistories Thank you! I'm working on one, will ping you when it's available 😎

machinehistories, 2024-11-05:
thanks appreciate it

peterzimon, 2024-12-15:
@machinehistories I've added BOMs and production files to all boards.

Also I've written a build guide here:

[https://www.shmoergh.com/hog-build-guide/](https://www.shmoergh.com/hog-build-guide/)

Hope it's useful ✌️

machinehistories, 2024-12-16:
thanks that's terrific

On Sun, Dec 15, 2024 at 5:15 AM Peter Zimon ***@***.***>
wrote:

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

Closed 2024-12-15.

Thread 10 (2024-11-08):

Add THT footprint to J111 in VCOs

peterzimon, 2024-11-08:
Having a dual footprint for the J111 prepares the circuit for potential SMD component shortage

Closed 2024-11-23.

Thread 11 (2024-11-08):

Update filter trimmer footprints to use horizontal ones

peterzimon, 2024-11-08:
At the moment it's vertical which makes it impossible to fine tune.

shmoergh, 2024-11-23:
Done with https://github.com/shmoergh/hog/issues/24

Closed 2024-11-23.

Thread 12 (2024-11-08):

Research and replace non-precision trimmers to SMD ones

peterzimon, 2024-11-08:
- [x] Research parts
- [ ] Replace 'em

shmoergh, 2024-11-23:
JLCPCB parts
100kΩ — C719186
10kΩ — C911365
50kΩ — C145161

shmoergh, 2024-11-23:
Changed plan: the available SMD components can only be set from the top (vertically) so the UI board would cover the trimpots making it non-accessible.

Closed 2024-11-23.

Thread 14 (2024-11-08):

Fix PWM input of VCO1

peterzimon, 2024-11-08:
PWM input of VCO1 should be directly connected to the output of VCO2, not to the output of the amount knob to make PWM value independent.

shmoergh, 2024-11-23:
Solved with https://github.com/shmoergh/hog/issues/24

Closed 2024-11-23.

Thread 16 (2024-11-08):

Add safety OR circuit to MIDI2CV power input

peterzimon, 2024-11-08:
Currently he USB power of the Pico on the MIDI2CV board is directly connested to the 5V output of the regulator which can cause damage in the connected computer if the synth is turned on. The circuit should be updated so that only the synth's own power supplies are used in this case.

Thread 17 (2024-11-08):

Create gerber files for each board

peterzimon, 2024-11-08:
Prepare all boards to be easy to order from JLCPCB.

- [x] Core board
- [x] UI board
- [x] PSU board
- [x] MIDI board
- [x] Filter board

Closed 2024-12-14.

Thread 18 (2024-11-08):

Add paraphonic mode via MIDI

peterzimon, 2024-11-08:
Paraphonic mode is only supported via CV input at the moment. It should work with MIDI too but it's not obvious how to implement it.

### Problem

At the moment the pitch of VCO 2 is normalized to the _glided_ pitch of VCO 1, and VCO 1 pitch is normalized to MIDI pitch. This makes sure that the pitch of the two VCOs are always the same. How to update this to allow two MIDI pitches set the two VCOs separately.

peterzimon, 2024-12-09:
The solution is not obvious, we'll opt for making MIDI work properly in monophonic mode (single CV from MIDI + glide on both voices) and keep CV-only paraphonic mode.

Closed 2024-12-09.

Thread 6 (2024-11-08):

Reposition VCO tuning trimpots

peterzimon, 2024-11-08:
At the moment, PSU board is in the way which makes it very hard to tune. Alternatively top-screw trimpots and holes on the UI board could work

peterzimon, 2024-11-30:
Closed with https://github.com/shmoergh/hog/commit/a9f9715e1053f44825b6762ae9e018dc59ed68b0

Closed 2024-11-30.

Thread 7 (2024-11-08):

Separate VCO thermal compensation options

peterzimon, 2024-11-08:
Currently the VCO circuit is designes with two potential ways to compensate thermal drifts to prepare for component shortage. Create two alternative circuits that only uses each, so it's simpler to order.

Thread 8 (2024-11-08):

Simplify VCA

peterzimon, 2024-11-08:
The CV rejection trimpot at the connection of the diff-pair collectors is almost never needed, since a single package transistor pair is used, and the drift voltage is minimal. The trimpot can be removed.

Closed 2024-11-23.

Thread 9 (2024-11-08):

Simplify Core/Mixer

peterzimon, 2024-11-08:
Use SMD resistor in the feedback loop of the first inverting amp. It's been THT for experimentation purposes

Closed 2024-11-23.

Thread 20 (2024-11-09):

Reconnect MIDI2CV pitch outputs

peterzimon, 2024-11-09:
Currently the "Fat pitch" jack input is defaulted to the normal CV (pitch) input. This doesn't allow to use the MIDI2CV converter to control the pitch of the "Fat" (2nd) voice with the same technique, ie. it's not possible to default the "Fat" pitch to both the output of the MIDI2CV converter's DAC and the normal CV.

Instead, the DAC outputs (pitch 1 and 2) from the MIDI2CV converter should be connected to the CV input of the two voices, respectively. This would decouple the MIDI CV from the CV jacks.

peterzimon, 2024-11-09:
Will be done via #18

Closed 2024-11-09.

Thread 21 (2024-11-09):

Use PWM for modwheel

peterzimon, 2024-11-09:
Currently one of the DAC output is used for the modwheel CV. Instead use PWM to set the voltage of Gate B so that the DAC output can be used to set the pitch of voise 2 ("Fat")

peterzimon, 2024-11-09:
Will be done via #18

Closed 2024-11-09.

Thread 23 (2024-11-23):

Add switch input for GATE mode

shmoergh, 2024-11-23:
In GATE mode the input voltage is arbitrary so to normalize it to a fixed voltage, a transistor switch for 8V should be added.

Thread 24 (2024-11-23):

Doublecheck all V2 to V3 bugs

shmoergh, 2024-11-23:
Go through all V2 bugs and check if they're all fixed in V3:

- [x] UI: Remove GND from pin 1 of GLIDED_PITCH switch, otherwise pitch will be grounded if tracking is off
- [x] UI: Set minimum LFO resistance to 220Ω
- [x] UI: Update LFO LED resistance values: 20kΩ for blue, 4.7kΩ for other color LEDs
- [x] UI: Set default pin of PITCH and GATE inputs to MIDI converter's respective outputs
- [x] UI: Add 12V power for MIDI2CV converter connector
- [x] UI: PWM of VCO1 should be connected directly to the max value of LFO2 not the one _after_ the AMOUNT pot
- [x] UI: Update dirty dual pot to 50kΩ (100kΩ is not available at Mouser)
- [x] UI: Update ring time dual pot to 500kΩ / 20mm (1MΩ is not available at Mouser)
- [x] Filter: remove C5 (470nF foil cap) from the AUDIO_IN. Gives a much-much nicer and fuller output
- [x] Filter: update R4 value to 3.3kΩ. This allows better minimum cutoff value
- [x] Filter: RV_BALANCE, RV_BIAS and RV_MAX_RESO trimpots have to be vertical for better accessibility

Closed 2024-11-23.

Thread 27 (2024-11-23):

Create streamlined only Core board

shmoergh, 2024-11-23:
There are a couple of circuit parts on the Core board that allow to choose different options to build:

- Builders can choose whether to use NTC or PTS100 based thermal compensation
- It has +/-5V outputs without using it on the Core board itself
- It has a power terminal that's not used
- There are both SMD and THT J111 footprints in the VCO

There should be an opinionated board which gets rid of all this and streamlines for a single, tested solution. This can only happen if all common fixes are applied already otherwise both boards have to be maintained.

peterzimon, 2024-11-30:
Closed with https://github.com/shmoergh/hog/commit/a9f9715e1053f44825b6762ae9e018dc59ed68b0

Closed 2024-11-30.

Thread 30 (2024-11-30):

Reposition Core board connectors to whole mm values

peterzimon, 2024-11-30:
Connectors have to be aligned on the 1mm grid on the Core board so that it's easy to align the connector pairs on the UI board.

Closed 2024-11-30.

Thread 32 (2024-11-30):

Normalize MIDI connections

peterzimon, 2024-11-30:
At the moment MIDI connectors use a few manual NTS connectors which require manual wiring by hand (cables). Instead MIDI should be connected via pins and pin headers just like the other boards.

Closed 2024-12-01.

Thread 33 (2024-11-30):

Update ON LED to support MIDI board's output

peterzimon, 2024-11-30:
The UI circuit should support both direct connection to 12V from the power rail (when MIDI board isn't used), and a pin from the MIDI board (when MIDI board is used).

peterzimon, 2024-12-01:
Closed with https://github.com/shmoergh/hog/issues/32

Closed 2024-12-01.

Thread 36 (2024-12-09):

Update drone mode gate voltage

peterzimon, 2024-12-09:
ATM the gate voltage for drone mode is fixed to 5V which makes it quieter than the normal gate. Drone mode gate voltage should be 8V.

Closed 2024-12-09.

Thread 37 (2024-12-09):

Remove IO backpanel connection

peterzimon, 2024-12-09:
The IO back panel connector on the UI board is a leftover from an earlier prototype. Can be removed.

Closed 2024-12-09.

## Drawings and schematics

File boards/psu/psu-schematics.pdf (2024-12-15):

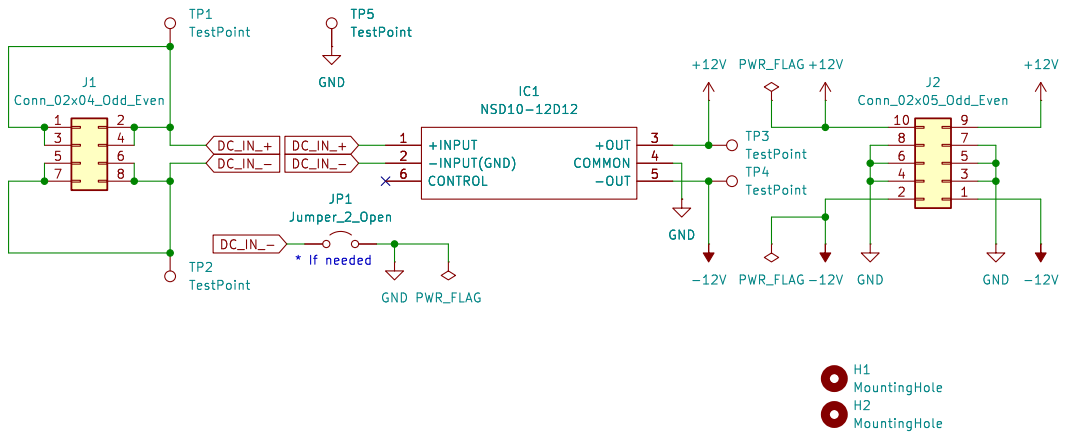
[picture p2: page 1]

Id: 1/1 Title: File: psu.kicad_sch Sheet: /

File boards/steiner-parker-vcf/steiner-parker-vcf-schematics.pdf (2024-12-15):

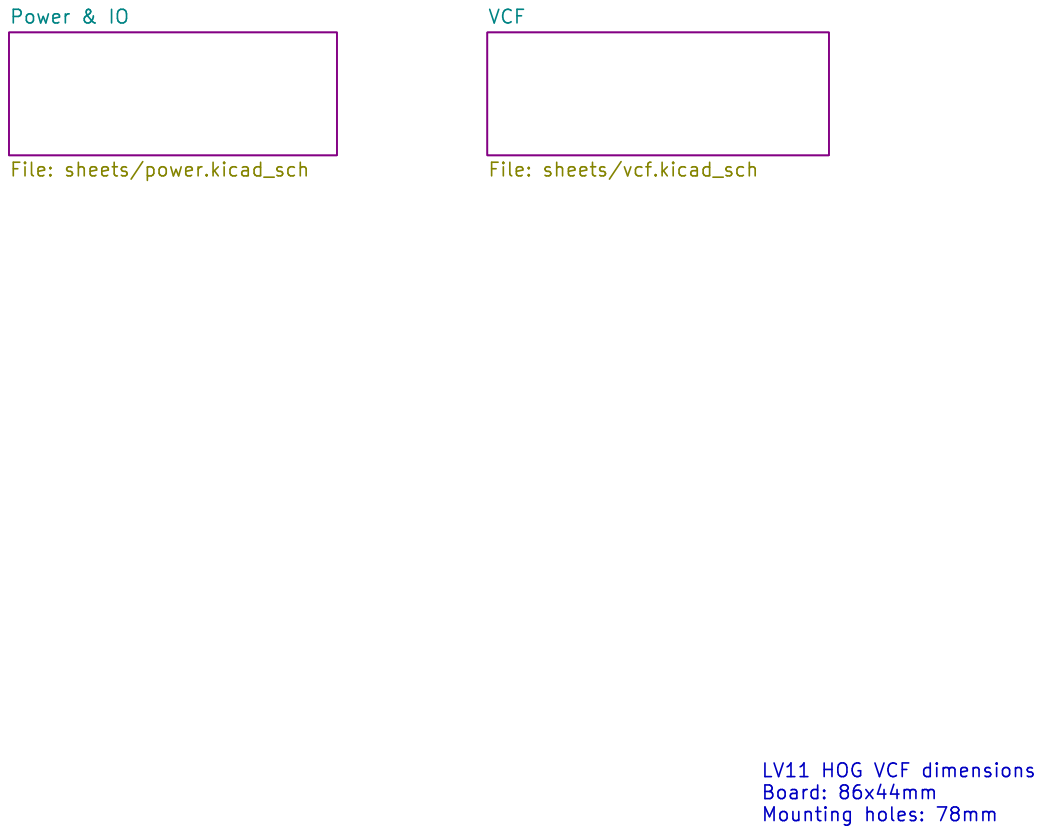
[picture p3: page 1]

LV11 HOG VCF dimensions Board: 86x44mm

File: steiner-parker-vcf.kicad_sch Sheet: / þÿShmøergh

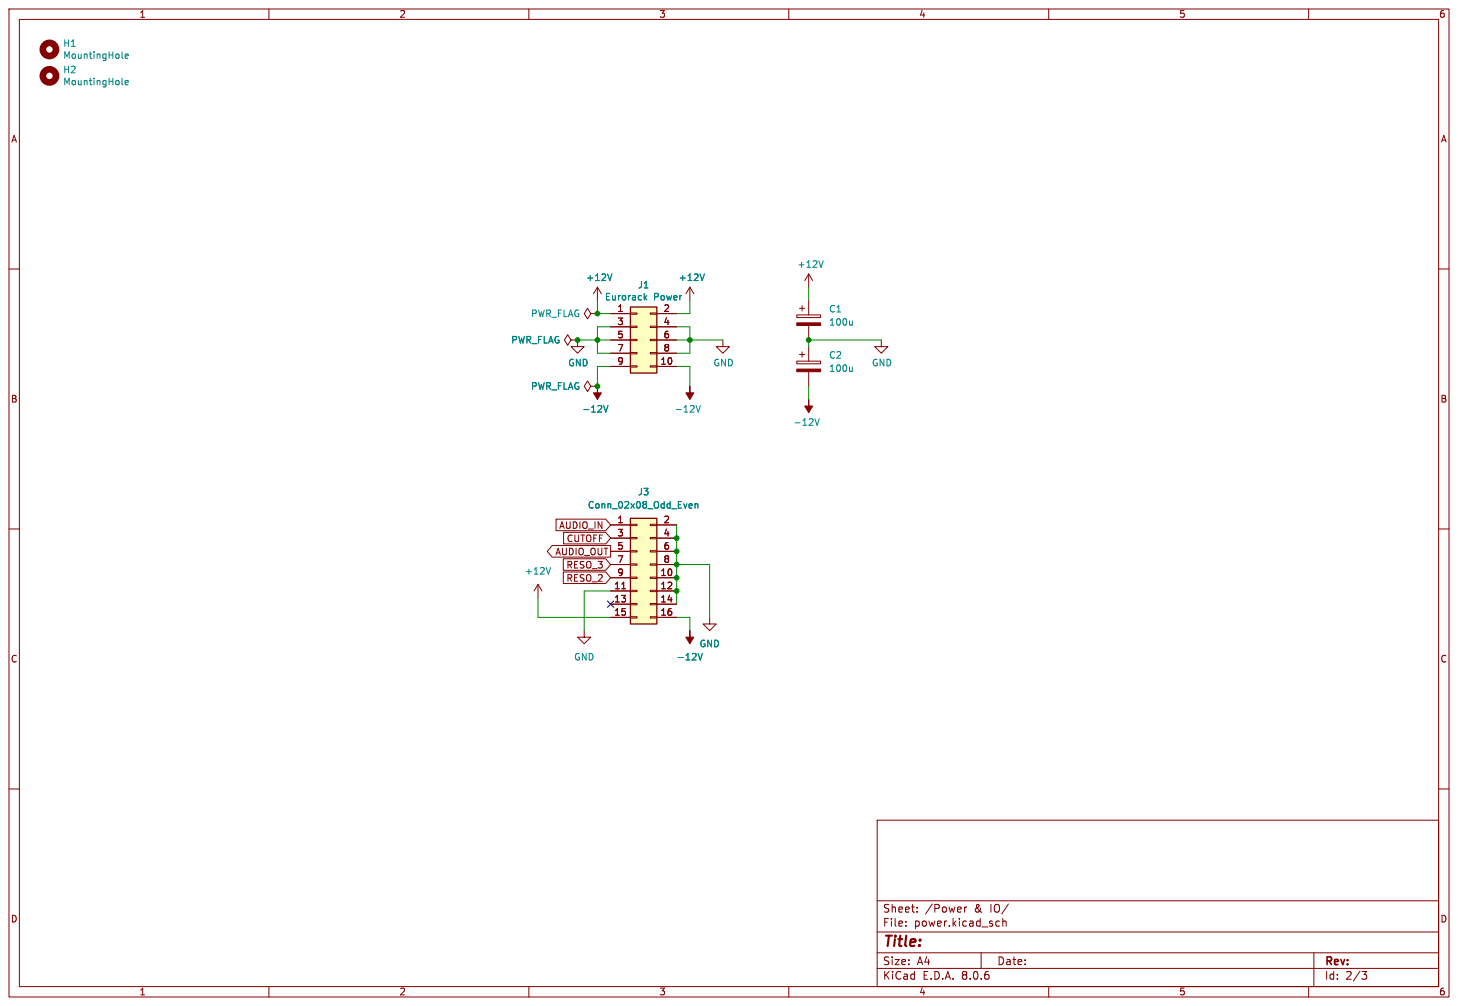
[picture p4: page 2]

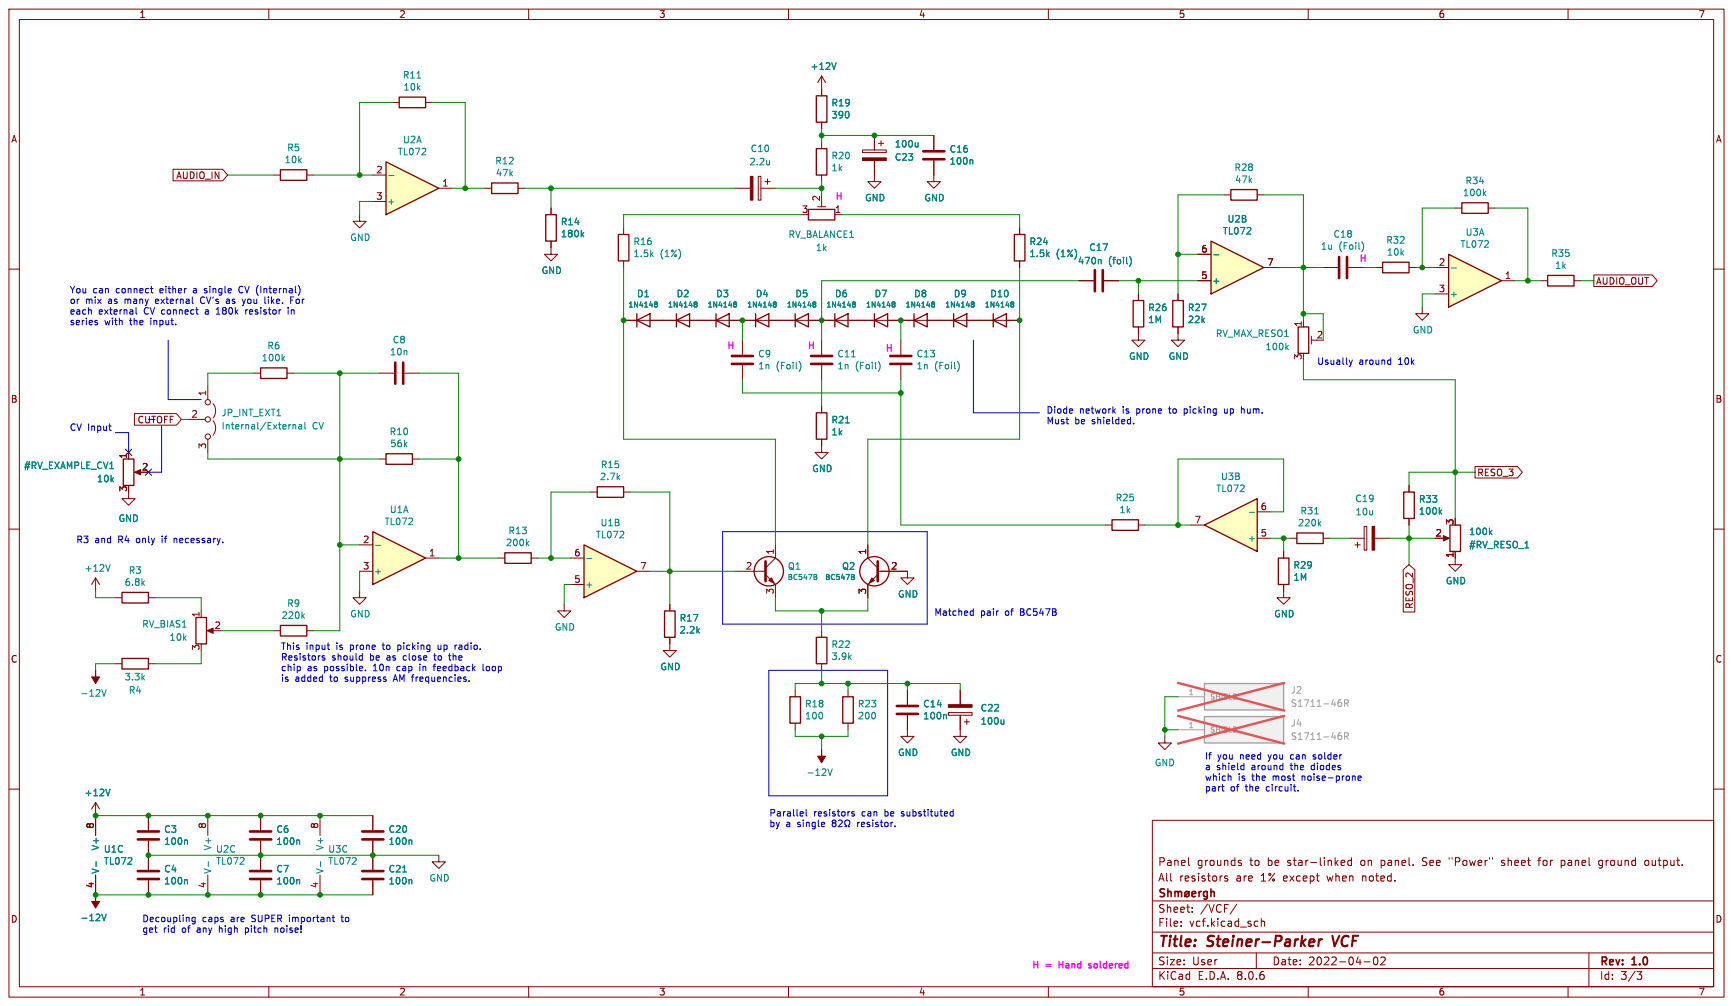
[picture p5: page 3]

is added to suppress AM frequencies.

If you need you can solder a shield around the diodes which is the most noise-prone

by a single þÿ82©resistor.

get rid of any high pitch noise!

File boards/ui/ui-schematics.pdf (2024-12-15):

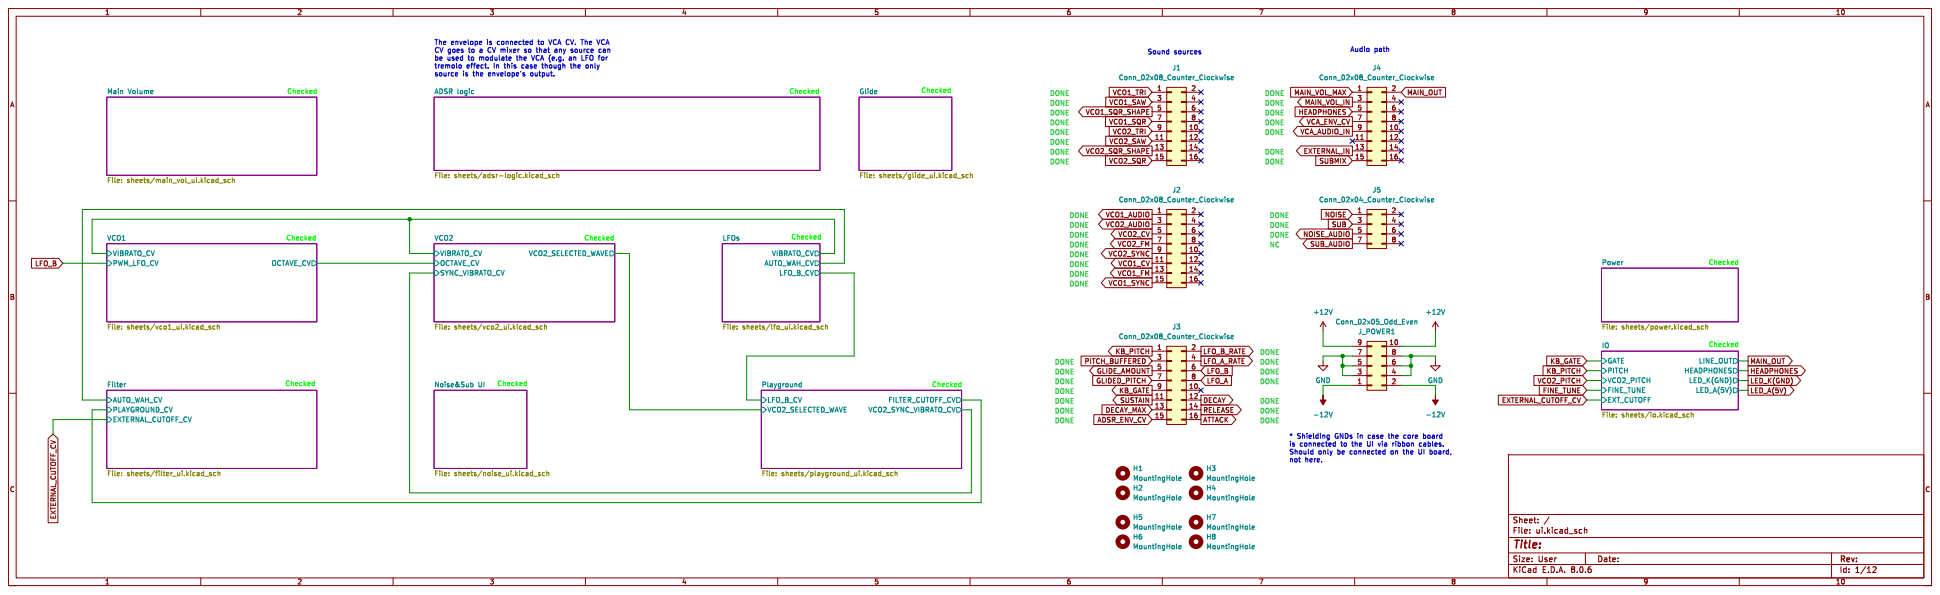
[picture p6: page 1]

File: sheets/io.kicad_sch Power File: sheets/power.kicad_sch Main Volume File: sheets/main_vol_ui.kicad_sch PLAYGROUND_CV

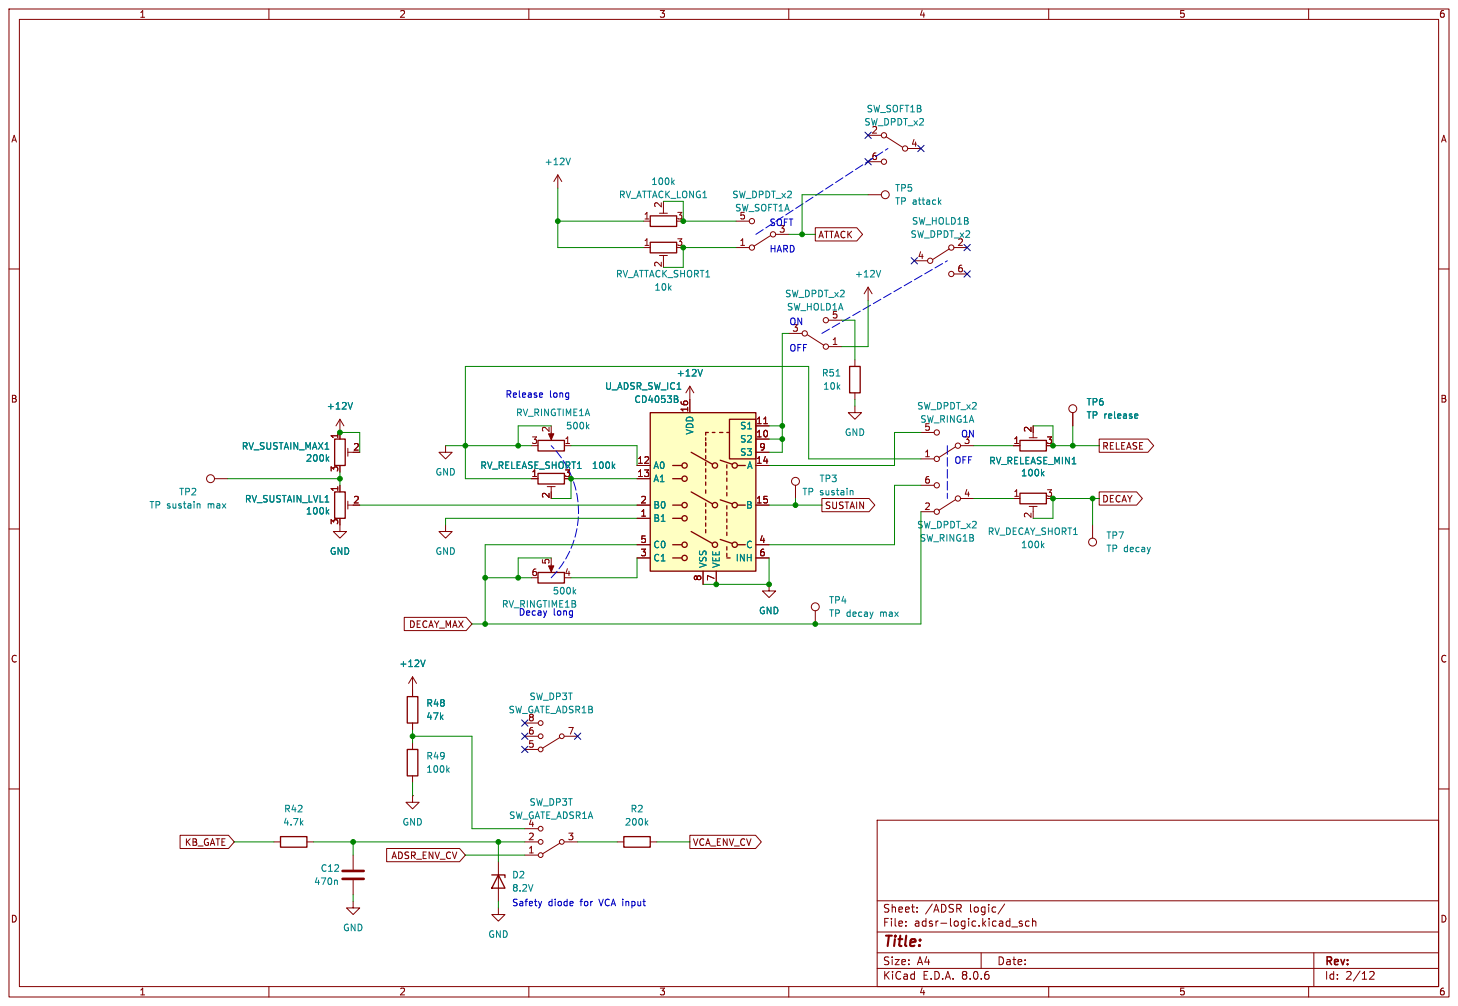
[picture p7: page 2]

RELEASE DECAY ONOFF SOFT HARD
SW_DPDT_x2 ATTACK

TP6 TP release TP7 TP decay 1
SW_DPDT_x2 GND GND

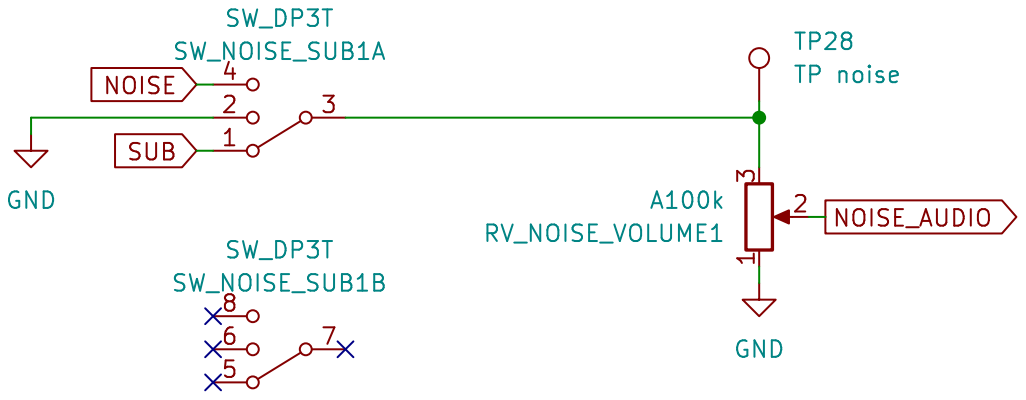
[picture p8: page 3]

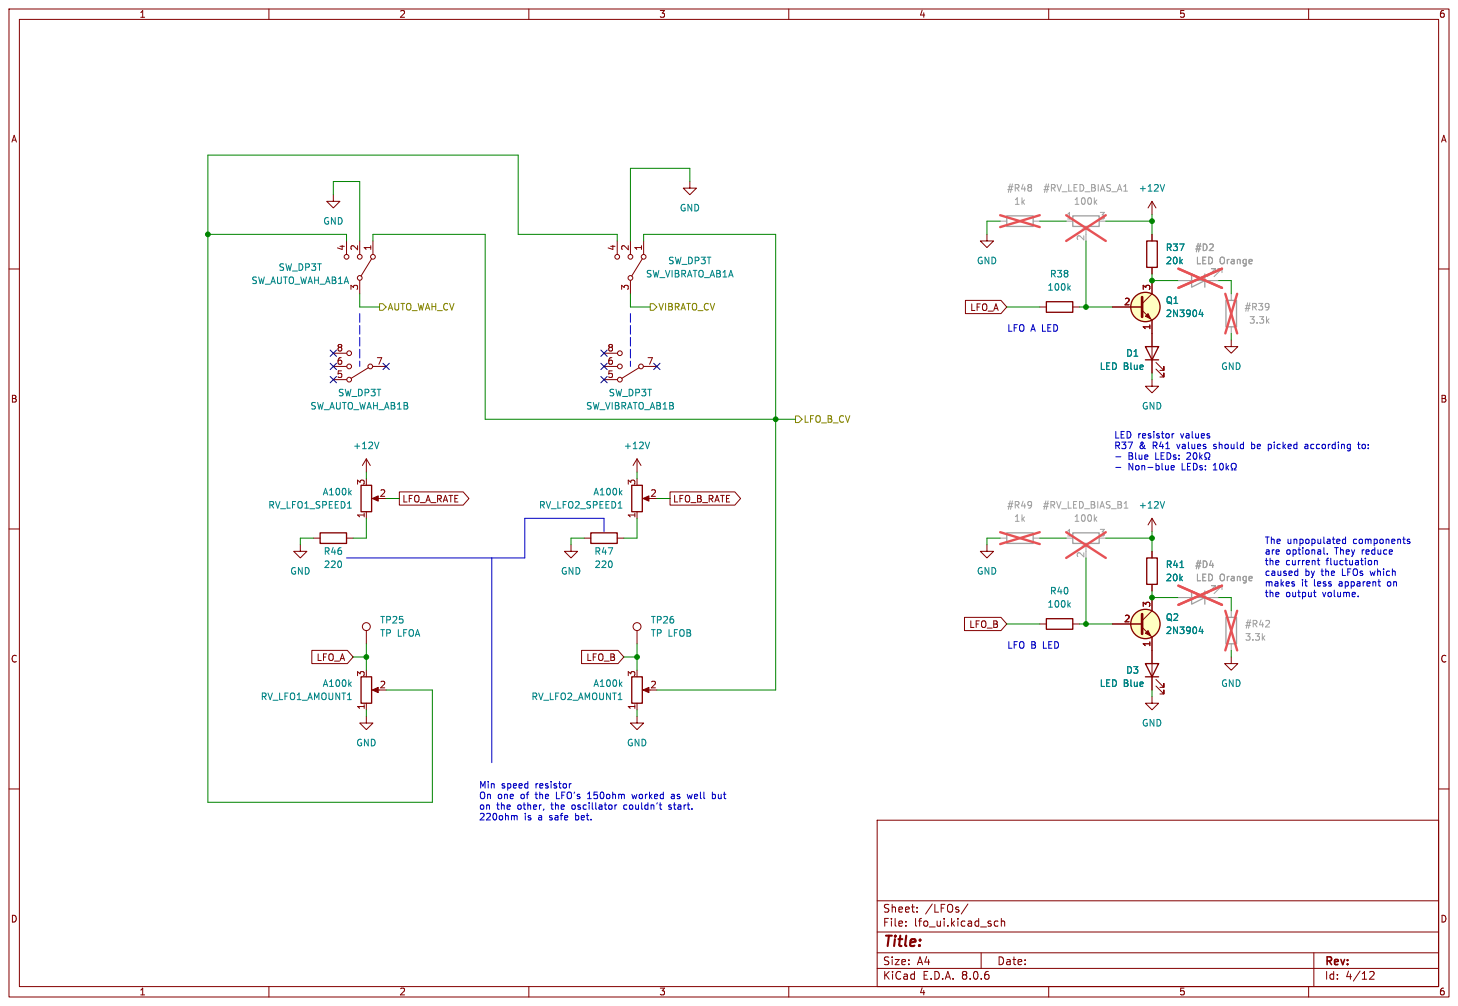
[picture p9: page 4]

the output volume. LFO B LED

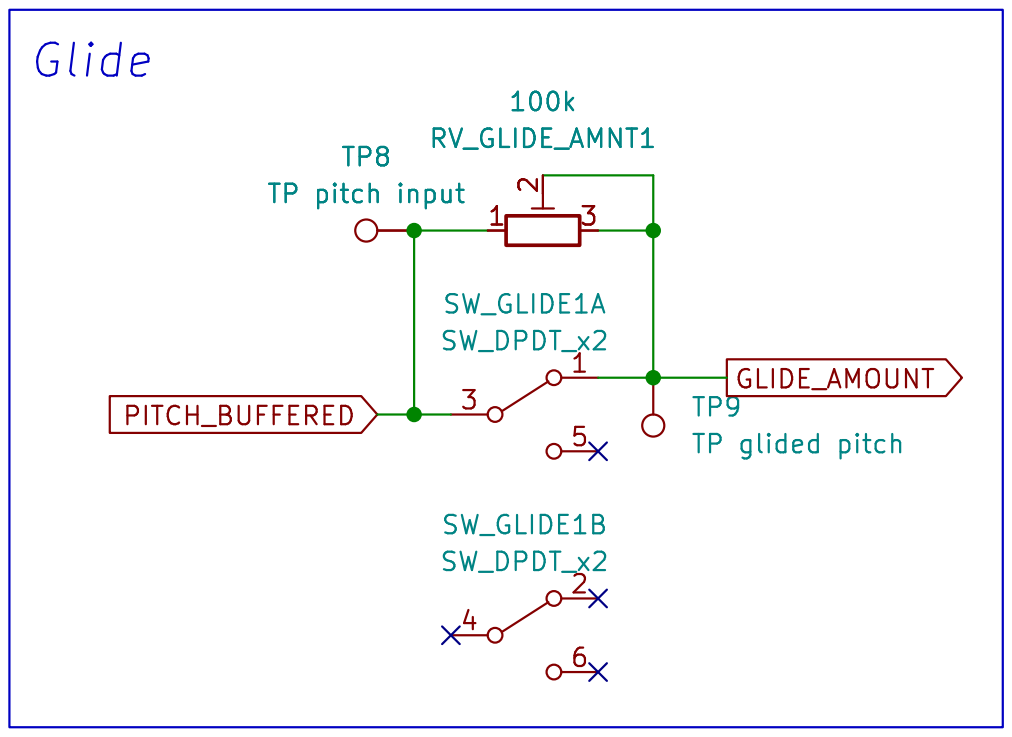
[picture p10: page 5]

Id: 5/12 Title: File: glide_ui.kicad_sch Sheet: /Glide/

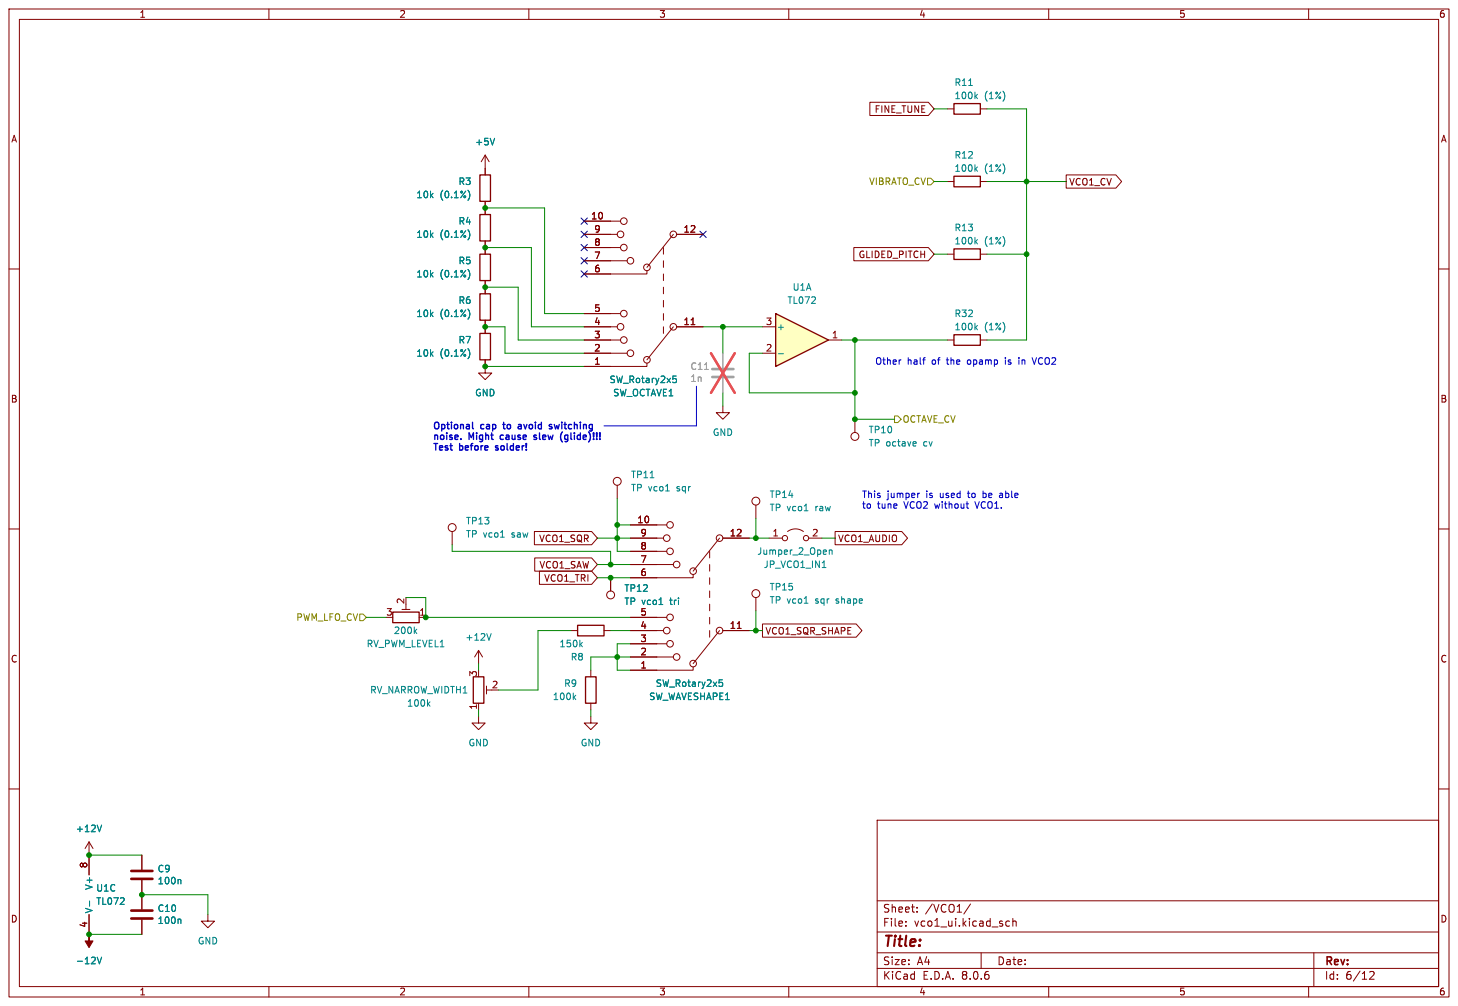
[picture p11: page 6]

GLIDED_PITCH Optional cap to avoid switching

to tune VCO2 without VCO1. Other half of the opamp is in VCO2

Id: 6/12 Title: File: vco1_ui.kicad_sch Sheet: /VCO1/

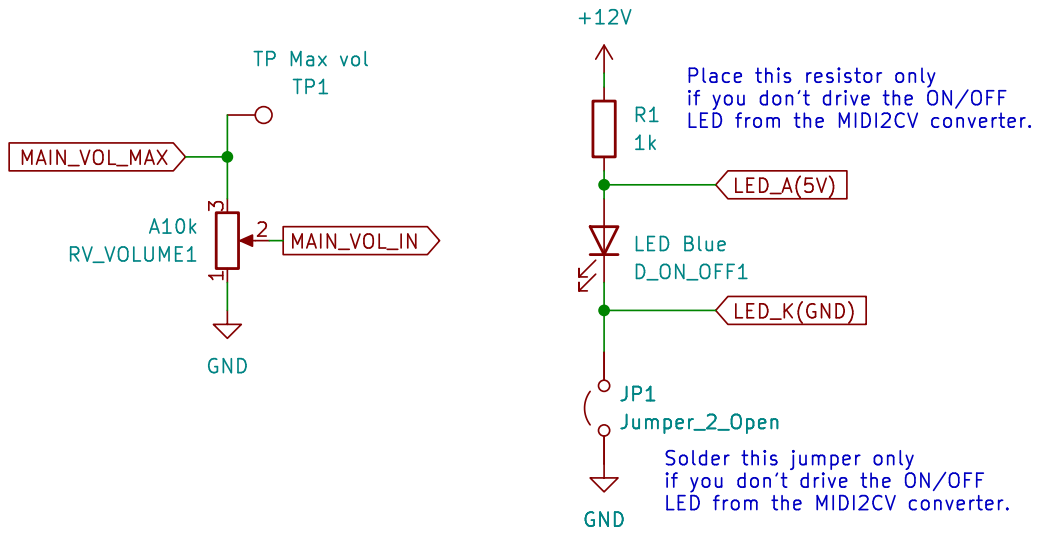
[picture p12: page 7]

if you don't drive the ON/OFF
LED from the MIDI2CV converter. Solder this jumper only
1kD_ON_OFF1

LED from the MIDI2CV converter. GND

Id: 7/12 Title: File: main_vol_ui.kicad_sch Sheet: /Main Volume/

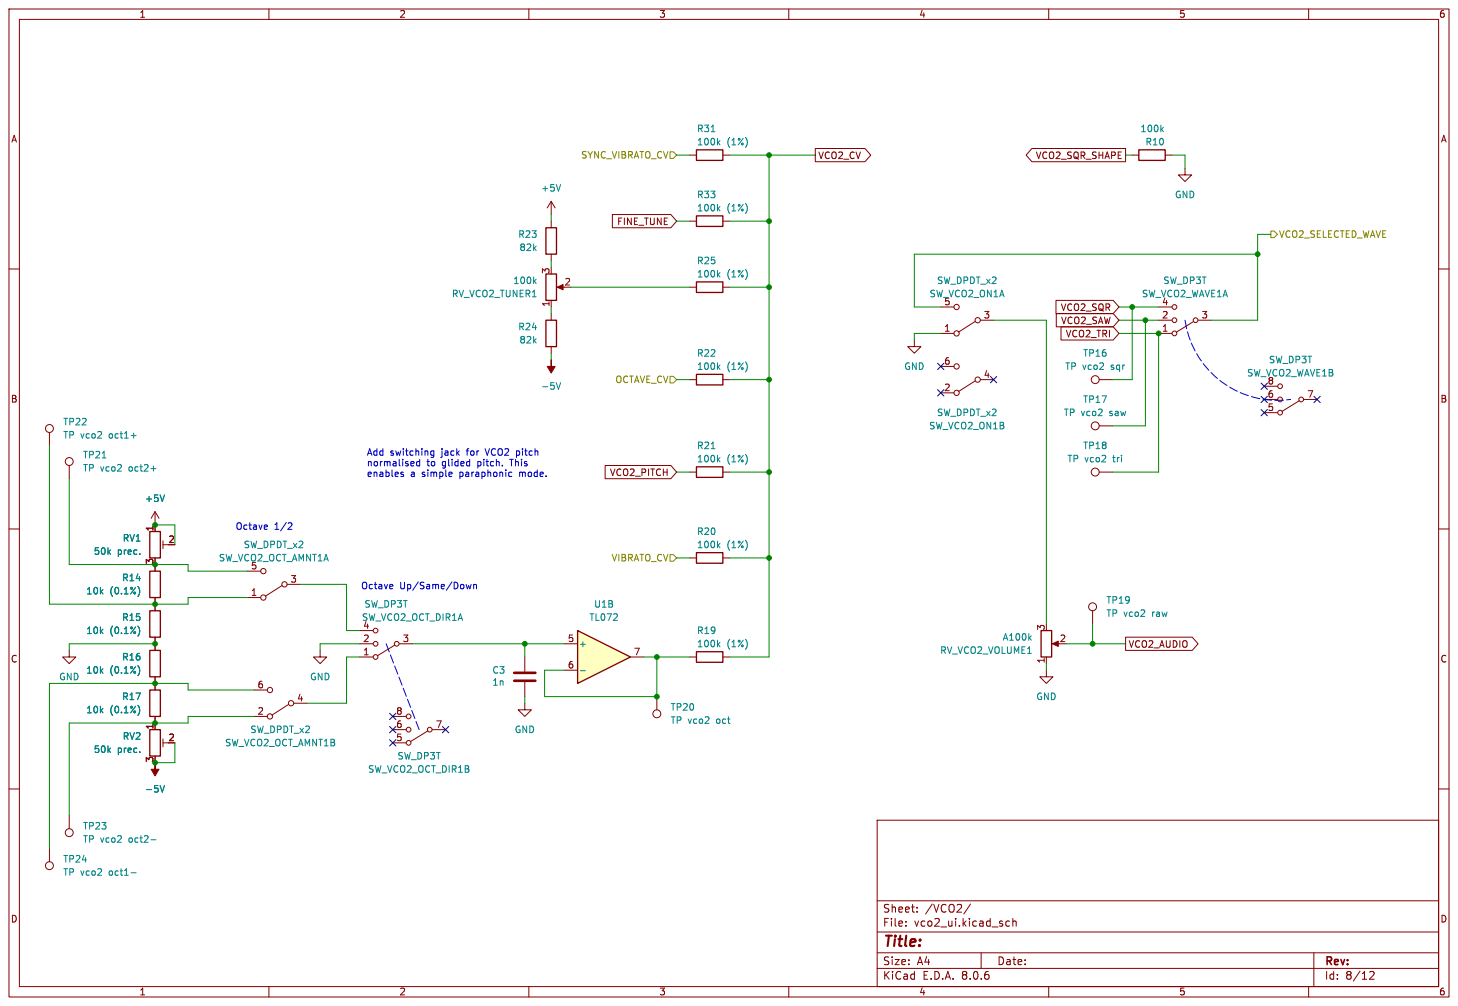
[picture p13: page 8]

Id: 8/12 Title: File: vco2_ui.kicad_sch Sheet: /VCO2/



Id: 10/12 Title: File: filter_ui.kicad_sch Sheet: /Filter/ 4


Id: 11/12 Title: File: power.kicad_sch Sheet: /Power/


noise inputs are avoided when there's no cable

plugged in. You can choose whether to use

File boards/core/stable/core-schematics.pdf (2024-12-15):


Power File: sheets/power.kicad_sch

SUB Noise + Sub File: sheets/noise-sub.kicad_schRAW_SAW

CV_INT CV_EXT VCO 2 File: sheets/vco.kicad_sch

VCO2 Waveshapers File: sheets/vco1-waveshapers.kicad_sch RAW_SAW

Buffers File: sheets/buffers.kicad_sch

Inputs and outputs are from the perspective
of this circuit.

File: core.kicad_sch Sheet: / þÿShmøergh

Id: 1/15 Title: Hog Analog Synth þÿ  Core


sync input H ONLY ONE OF THESE J111's SHOULD BE SOLDERED. Q215 is a THT footprint

Play a very high pitch note and start turning the trimpot so that the pitch is going down. Once it doesn't go lower

to C4 (261.63Hz) 4. Play C1 and use R_WIDTH to tune it to 32.703Hz) LOOP 3 + 4

5. When C1 and C4 are in tune, play higher octave C's and use R_HIFREQ to adjust tuning for them.

If needed, repeat steps 3 and 4 for other note pairs.

Id: 2/15 Title: VCO Core

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

Set output to C0 with BIAS when

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

5. When C1 and C4 are in tune, play higher octave C's and use R_HIFREQ to adjust tuning for them.

If needed, repeat steps 3 and 4 for other note pairs.

Id: 3/15 Title: VCO Core


to use it. External CV input should use 200k

File: vca.kicad_sch Sheet: /VCA/ TP226


up radio noise. Breakout for using the synth with
EXTERNAL_INPUT NOISE

fixed volume sound sources (VCO 1, NOISE). H

Id: 4/15 Title: Mixer File: mixer.kicad_sch Sheet: /Mixer/ C275


Square pulse width
----------------- Connect any number of CV inputs through input resistors

to set the pulse width with a CV on SQR_SHAPE. Use the

Use bias to set the center of

be used if needeed. Tests didn't show much diff.


File: adsr.kicad_sch Sheet: /ADSR/
Id: 6/15 Title: ADSR


From VCA
10Vpp (To set output gain use the VCA

then the output starts out with a very negative

this results in a very sharp and big spike
care of that and clips the output at a given
value. The red LEDs are quite good to limit

Id: 7/15 Title: Output File: output.kicad_sch Sheet: /Output/


H Glide control PITCH_BUFFERED
File: glide.kicad_sch Sheet: /Glide/ GND

1u (foil or electrolite) GND


File: lfos.kicad_sch Sheet: /LFO A/ -12VV- 4 V+

Id: 9/15 Title: Dual LFO


Id: 10/15 Title: Dual LFO



Used for VCO current source H
+12V GND

Id: 12/15 Title: Power File: power.kicad_sch Sheet: /Power/


Square pulse width
----------------- Connect any number of CV inputs through input resistors

to set the pulse width with a CV on SQR_SHAPE. Use the

Use bias to set the center of

be used if needeed. Tests didn't show much diff.


LFO_B_OUT
Id: 14/15 Title: File: buffers.kicad_sch Sheet: /Buffers/ TP231

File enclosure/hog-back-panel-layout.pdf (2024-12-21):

246

263

OUT; GATE; PITCH; VCO2 PITCH; EXT CUTOFF; MIDI IN; FINE TUNE 9mm (ø7); ON/OFF 10.5mm (ø8.8); Jack; Pot; Switch; Socket

HOG Back Panel Layout

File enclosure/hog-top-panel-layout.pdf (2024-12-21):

rotary; pot; LED; Top: 0,0

HOG Top Panel Layout

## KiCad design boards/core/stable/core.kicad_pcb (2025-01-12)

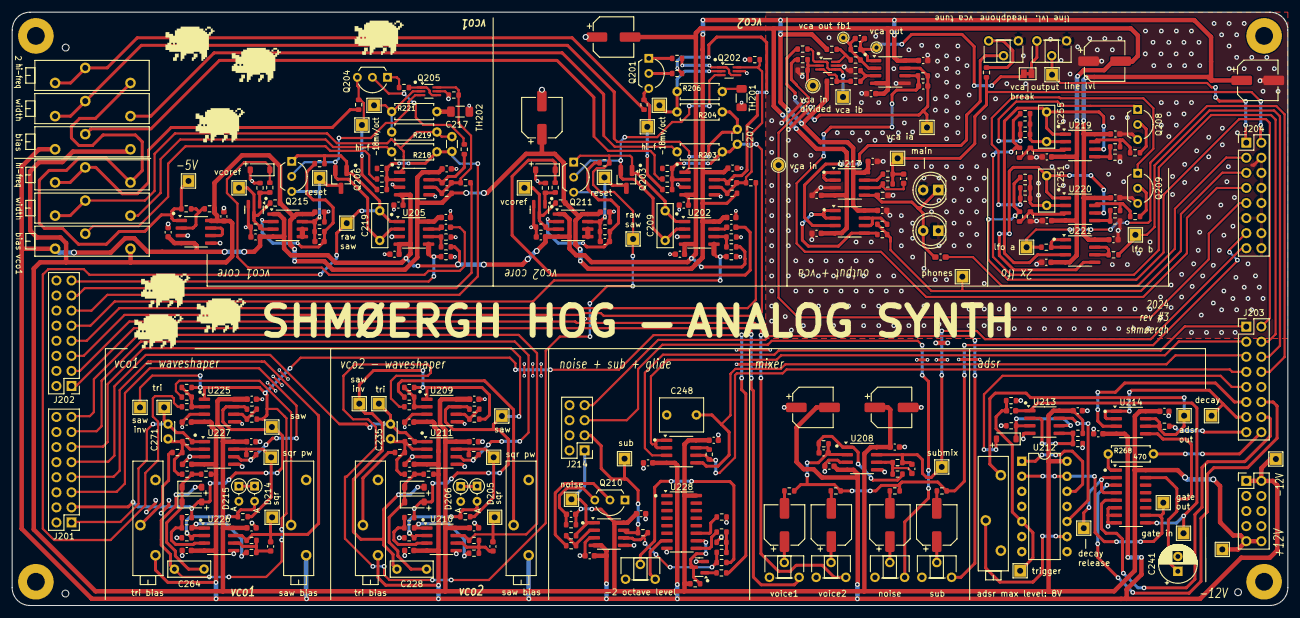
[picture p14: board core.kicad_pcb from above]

Board: 2 copper layers, 215.0 x 100.0 mm, 351 parts (0 on the bottom side), 186 nets.

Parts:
C201, C202, C203, C204, C205, C206, C211, C212, C213, C214, C215, C216, C221, C222, C223, C224, C229, C230, C231, C232, C233, C234, C237, C238, C239, C242, C243, C244, C245, C246, C247, C249, C250, C253, C254, C257, C258, C259, C262, C263, C265, C266, C267, C268, C269, C270, C278, C279: 100n; C_0603_1608Metric
C207, C217: 100p-1n; C_Disc_D3.0mm_W1.6mm_P2.50mm
C208, C218, C276: 100p; C_0603_1608Metric
C209, C219: 2.2nF (foil); C_Rect_L7.2mm_W2.5mm_P5.00mm_FKS2_FKP2_MKS2_MKP2
C210, C220: 22p; C_0603_1608Metric
C225, C226, C227, C275: 22uF; CP_Elec_6.3x5.4
C228, C264: 10p-100p; C_Rect_L7.0mm_W2.5mm_P5.00mm
C235, C271: 22p; C_Disc_D3.0mm_W2.0mm_P2.50mm
C236, C272: 33p; C_0603_1608Metric
C240: 10n; C_0603_1608Metric
C241: 10u; CP_Radial_D6.3mm_P2.50mm
C248: 1u (foil or electrolite); C_Rect_L7.2mm_W5.5mm_P5.00mm_FKS2_FKP2_MKS2_MKP2
C251, C255: 22n-47n (foil); C_Rect_L7.0mm_W2.5mm_P5.00mm
C252, C256, C280, C281: 47u; CP_Elec_6.3x5.4
C260, C261: 100u; CP_Elec_6.3x7.7
C273, C274, C282, C283, C284, C285: 47p; C_0603_1608Metric
C277: 1u; C_0603_1608Metric_Pad1.08x0.95mm_HandSolder
D203, D204, D207, D212, D213, D216, D217: 1N4148; D_SOD-123
D205, D206, D214, D215: 5.1V; D_DO-34_SOD68_P2.54mm_Vertical_AnodeUp
D_NEGATIVE_LIMITER201: Red LED; LED_D5.0mm
D_POSITIVE_LIMITER201: Red LED; LED_D5.0mm
H201, H202, H203, H204: MountingHole; MountingHole_3mm_Pad
J201, J202, J203, J204: Conn_02x08_Counter_Clockwise; PinHeader_2x08_P2.54mm_Vertical
J214: Conn_02x04_Counter_Clockwise; PinHeader_2x04_P2.54mm_Vertical
JP202: Breakpoint; SolderJumper-2_P1.3mm_Bridged_Pad1.0x1.5mm
J_POWER201: Conn_02x05_Odd_Even; PinHeader_2x05_P2.54mm_Vertical
Q201, Q204: 2N3906; TO-92L_Inline_Wide
Q202, Q205, Q207: BC847BS; SOT-363_SC-70-6_Handsoldering
Q203, Q206: MMBFJ111; SOT-23_Handsoldering
Q208, Q209, Q210: BC548C; TO-92L_Inline_Wide
Q211, Q215: J111; TO-92_Inline_Wide
Q212, Q213, Q214: MMBT5551; SOT-23
R201, R213, R216, R228, R232, R235, R237, R242, R243, R244, R246, R247, R250, R252, R253, R254, R255, R262, R263, R264, R278, R279, R280, R281, R282, R283, R284, R285, R286, R287, R301, R304, R306, R307, R308, R309, R316, R317, R318, R319, R326, R327, R328, R329, R335, R336, R337, R338, R339, R340: 100k; R_0603_1608Metric
R202, R212, R217, R227: 150k; R_0603_1608Metric
R203, R218: 91k; R_Axial_DIN0207_L6.3mm_D2.5mm_P7.62mm_Horizontal
R204, R219: 6.2k (50ppm); R_Axial_DIN0207_L6.3mm_D2.5mm_P7.62mm_Horizontal
R205, R208, R220, R223, R322, R323: 1M; R_0603_1608Metric
R206, R221: 4R22 (50ppm); R_Axial_DIN0207_L6.3mm_D2.5mm_P7.62mm_Horizontal
R207, R209, R222, R224: 1.5k; R_0603_1608Metric
R210, R225: 510; R_0603_1608Metric
R211, R226: 22k; R_0603_1608Metric
R214, R229: 330k; R_0603_1608Metric
R215, R230, R258, R297, R312: 2.2k; R_0603_1608Metric
R231: 4.7k; R_0603_1608Metric
R233: 220; R_0603_1608Metric
R234, R245: 33k; R_0603_1608Metric
R236, R238, R239, R266, R288, R289, R324, R325: 10k; R_0603_1608Metric
R240, R241, R296: 470k; R_0603_1608Metric
R248, R249, R302, R303: 15k; R_0603_1608Metric
R251, R305: 27k; R_0603_1608Metric
R256, R259, R310, R313, R320: 220k; R_0603_1608Metric
R257, R267, R290, R291, R292, R293, R311, R321, R330, R331, R332, R333, R334: 47k; R_0603_1608Metric
R260, R314: 2.2M; R_0603_1608Metric
R261, R300, R315: 240k; R_0603_1608Metric
R265: 75k; R_0603_1608Metric
R268: 470; R_Axial_DIN0207_L6.3mm_D2.5mm_P7.62mm_Horizontal
R269, R272, R277, R294, R295: 1k; R_0603_1608Metric
R270: 100k; R_0603_1608Metric_Pad0.98x0.95mm_HandSolder
R271: 150; R_0603_1608Metric
R273, R274: 100; R_0603_1608Metric
R298: 3.3M; R_0603_1608Metric
RV201, RV202, RV203, RV204, RV205: 100k; Potentiometer_ACP_CA6-H2,5_Horizontal
RV_ADSR_MAX_VOLTAGE201: 100k; Potentiometer_Bourns_3006P_Horizontal
RV_HEADPHONE_LIM201: 100k; Potentiometer_ACP_CA6-H2,5_Horizontal
RV_LINE_OUT_LVL201: 10k; Potentiometer_ACP_CA6-H2,5_Horizontal
RV_SAW_BIAS201, RV_SAW_BIAS202: 10k; Potentiometer_Bourns_3006P_Horizontal
RV_TRI_BIAS201, RV_TRI_BIAS202: 100k; Potentiometer_Bourns_3006P_Horizontal
R_BIAS201, R_BIAS203: 100k (prec); Potentiometer_Bourns_3006P_Horizontal
R_HIFREQ201, R_HIFREQ202: 2k (prec); Potentiometer_Bourns_3006P_Horizontal
R_WIDTH201, R_WIDTH202: 20k; Potentiometer_Bourns_3006P_Horizontal
TH201, TH202: PTS120601B100RP100; R_1206_3216Metric_Pad1.30x1.75mm_HandSolder
TP201, TP205: -18mV/V; TestPoint_THTPad_2.0x2.0mm_Drill1.0mm
TP202, TP206: HiFreq; TestPoint_THTPad_2.0x2.0mm_Drill1.0mm
TP203, TP207: VCOVREF; TestPoint_THTPad_2.0x2.0mm_Drill1.0mm
TP204, TP208: Reset OUT; TestPoint_THTPad_2.0x2.0mm_Drill1.0mm
TP209, TP210: SAWInv; TestPoint_THTPad_2.0x2.0mm_Drill1.0mm
TP211, TP212: SAW; TestPoint_THTPad_2.0x2.0mm_Drill1.0mm
TP213, TP214: TRI; TestPoint_THTPad_2.0x2.0mm_Drill1.0mm
TP215, TP216: PW; TestPoint_THTPad_2.0x2.0mm_Drill1.0mm
TP217, TP218: SQR; TestPoint_THTPad_2.0x2.0mm_Drill1.0mm
TP219: NOISE; TestPoint_THTPad_2.0x2.0mm_Drill1.0mm
TP220: DR_OUT; TestPoint_THTPad_2.0x2.0mm_Drill1.0mm
TP221: TRIG; TestPoint_THTPad_2.0x2.0mm_Drill1.0mm
TP222: Gate2; TestPoint_THTPad_2.0x2.0mm_Drill1.0mm
TP223: Gate1; TestPoint_THTPad_2.0x2.0mm_Drill1.0mm
TP224: Submix; TestPoint_THTPad_2.0x2.0mm_Drill1.0mm
TP225: IVCA_A; TestPoint_THTPad_2.0x2.0mm_Drill1.0mm
TP226: IVCA_B; TestPoint_THTPad_2.0x2.0mm_Drill1.0mm
TP227: MAINOUT; TestPoint_THTPad_2.0x2.0mm_Drill1.0mm
TP228: MAX_LINEOUT; TestPoint_THTPad_2.0x2.0mm_Drill1.0mm
TP229: PHONES_OUT; TestPoint_THTPad_2.0x2.0mm_Drill1.0mm
TP230: LFO_A_OUT; TestPoint_THTPad_2.0x2.0mm_Drill1.0mm
TP231: LFO_B_OUT; TestPoint_THTPad_2.0x2.0mm_Drill1.0mm
TP232: SUB; TestPoint_THTPad_2.0x2.0mm_Drill1.0mm
TP233, TP234: RAW_SAW; TestPoint_THTPad_2.0x2.0mm_Drill1.0mm
TP235: 12V; TestPoint_THTPad_2.0x2.0mm_Drill1.0mm
TP236: -12V; TestPoint_THTPad_2.0x2.0mm_Drill1.0mm
TP237: -5V; TestPoint_THTPad_2.0x2.0mm_Drill1.0mm
TP_ADSR_OUT201: TestPoint; TestPoint_THTPad_2.0x2.0mm_Drill1.0mm
TP_SUSTAIN201: Sustain; TestPoint_THTPad_2.0x2.0mm_Drill1.0mm
TP_VCA_AU_IN201: VCA_IN_DIV; TestPoint_THTPad_D2.0mm_Drill1.0mm
TP_VCA_AU_IN202: VCA_IN; TestPoint_THTPad_D2.0mm_Drill1.0mm
TP_VCA_OUT201: VCA_OUT; TestPoint_THTPad_D1.5mm_Drill0.7mm
TP_VCA_OUT202: VCA_OUT_FB; TestPoint_THTPad_D1.5mm_Drill0.7mm
U201, U202, U204, U205, U207, U208, U209, U210, U211, U214, U217, U218, U219, U220, U221, U222, U223, U225, U226, U227: TL072; SOIC-8_3.9x4.9mm_P1.27mm
U203, U206: LM311; SOIC-8_3.9x4.9mm_P1.27mm
U212: 4002; DIP-14_W7.62mm
U213: LM358; SOIC-8_3.9x4.9mm_P1.27mm
U215: CD4053B; SOIC-16_3.9x9.9mm_P1.27mm
U216: NE5532; SOIC-8_3.9x4.9mm_P1.27mm
U228: CD4040BM96; SOIC-16_3.9x9.9mm_P1.27mm

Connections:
+12V: C201.1, C203.1, C205.1, C211.1, C213.1, C215.1, C221.1, C223.1, C229.1, C231.1, C233.1, C237.1, C238.1, C242.1, C244.1, C246.1, C249.1, C252.1, C253.1, C257.1, C258.1, C260.1, C262.1, C265.1, C267.1, C269.1, C278.1, C280.1, J_POWER201.9, J_POWER201.10, R208.1, R212.2, R223.1, R227.2, R235.2, R237.2, R265.1, R296.1, R300.1, R321.1, R_BIAS201.1, R_BIAS203.1, TP235.1, U201.8 (V+), U202.8 (V+), U203.8 (V+), U204.8 (V+), U205.8 (V+), U206.8 (V+), U207.8 (V+), U208.8 (V+), U209.8 (V+), U210.8 (V+), U211.8 (V+), U212.14 (VDD), U213.8 (V+), U214.8 (V+), U215.16 (VDD), U216.8 (V+), U217.8 (V+), U218.8 (V+), U219.8 (V+), U220.8 (V+), U221.8 (V+), U222.8 (V+), U223.8 (V+), U225.8 (V+), U226.8 (V+), U227.8 (V+), U228.16 (VDD)
-5V: R301.2, R_HIFREQ201.1, R_HIFREQ202.1, TP237.1, U223.1
-12V: C202.2, C204.2, C206.2, C212.2, C214.2, C216.2, C222.2, C224.2, C230.2, C232.2, C234.2, C239.2, C243.2, C245.2, C247.2, C250.2, C254.2, C256.2, C259.2, C261.2, C263.2, C266.2, C268.2, C270.2, C279.2, C281.2, J_POWER201.1, J_POWER201.2, R250.2, R304.2, R326.2, R327.2, RV_SAW_BIAS201.3, RV_SAW_BIAS202.3, RV_TRI_BIAS201.3, RV_TRI_BIAS202.3, R_BIAS201.3, R_BIAS203.3, TP236.1, U201.4 (V-), U202.4 (V-), U203.1 (GND), U203.4 (V-), U204.4 (V-), U205.4 (V-), U206.1 (GND), U206.4 (V-), U207.4 (V-), U208.4 (V-), U209.4 (V-), U210.4 (V-), U211.4 (V-), U214.4 (V-), U216.4 (V-), U217.4 (V-), U218.4 (V-), U219.4 (V-), U220.4 (V-), U221.4 (V-), U222.4 (V-), U223.4 (V-), U225.4 (V-), U226.4 (V-), U227.4 (V-)
/Buffers/LFO_A_IN: C255.1, U219.1, U219.6 (-), U221.3 (+)
/Buffers/LFO_B_IN: C251.1, U220.1, U220.6 (-), U221.5 (+)
/Output/AUDIO_IN: JP202.1 (A), RV_LINE_OUT_LVL201.3
/VCA/VCA_AUDIO_OUT: C285.2, JP202.2 (B), R241.2, TP_VCA_OUT201.1, U207.1
/VCO1 Waveshapers/SAW_INV: C264.2, D213.2 (A), R305.1, R308.2, R320.2, TP210.1, U225.1
/VCO2 Waveshapers/SAW_INV: C228.2, D204.2 (A), R251.1, R254.2, TP209.1, U209.1
/VCO 2/HI_FREQ_COMP: Q201.3 (C), R202.2, R210.1, TP202.1
/VCO 2/I_REF: C208.1, Q202.6 (C1), R205.2, R208.2, R339.2, U201.6 (-)
/VCO 2/RAW_SAW: C209.2, Q203.1 (D), Q211.1 (D), R211.1, R248.2, TP233.1, U202.1
/VCO/HI_FREQ_COMP: Q204.3 (C), R217.2, R225.1, TP206.1
/VCO/I_REF: C218.1, Q205.6 (C1), R220.2, R223.2, R340.2, U204.6 (-)
/VCO/RAW_SAW: C219.2, Q206.1 (D), Q215.1 (D), R226.1, R302.2, TP234.1, U205.1
ADSR_ENV_CV: J203.15, R269.1
ATTACK: J203.16, R268.2
DECAY: J203.12, U215.3 (C1)
DECAY_MAX: J203.13, TP_SUSTAIN201.1, U214.1, U214.2 (-)
EXTERNAL_INPUT: C282.1, J204.13, R242.2, R243.2, R244.2, R245.1, R338.2, U208.2 (-)
GLIDED_PITCH: J203.7, R277.1, U218.6 (-)
GLIDE_AMOUNT: C248.1, J203.5, U218.5 (+)
GND: C201.2, C202.1, C203.2, C204.1, C205.2, C206.1, C211.2, C212.1, C213.2, C214.1, C215.2, C216.1, C221.2, C222.1, C223.2, C224.1, C229.2, C230.1, C231.2, C232.1, C233.2, C234.1, C237.2, C238.2, C239.1, C241.2, C242.2, C243.1, C244.2, C245.1, C246.2, C247.1, C248.2, C249.2, C250.1, C252.2, C253.2, C254.1, C256.1, C258.2, C259.1, C260.2, C261.1, C262.2, C263.1, C265.2, C266.1, C267.2, C268.1, C269.2, C270.1, C278.2, C279.1, C280.2, C281.1, D206.2 (A), D215.2 (A), D216.2 (A), D217.2 (A), D_NEGATIVE_LIMITER201.2 (A), D_POSITIVE_LIMITER201.1 (K), J201.2, J201.4, J201.6, J201.8, J201.10, J201.12, J201.14, J201.16, J202.2, J202.4, J202.6, J202.8, J202.10, J202.12, J202.14, J202.16, J204.4, J204.6, J204.8, J204.10, J204.11, J204.12, J204.14, J204.16, J214.2, J214.4, J214.6, J214.8, J_POWER201.3, J_POWER201.4, J_POWER201.5, J_POWER201.6, J_POWER201.7, J_POWER201.8, Q202.5 (B2), Q205.5 (B2), Q207.5 (B2), Q208.3 (E), Q209.3 (E), Q212.2 (E), Q213.2 (E), Q214.2 (E), R213.1, R215.2, R228.1, R230.2, R233.2, R240.1, R259.2, R264.1, R266.2, R267.2, R270.1, R286.2, R287.2, R290.2, R291.2, R313.2, R322.2, R323.2, R324.1, R325.1, R330.2, R331.2, R332.2, R334.1, R339.1, R340.1, RV201.1, RV202.1, RV203.1, RV204.1, RV205.1, RV_ADSR_MAX_VOLTAGE201.3, RV_HEADPHONE_LIM201.1, RV_LINE_OUT_LVL201.1, RV_SAW_BIAS201.1, RV_SAW_BIAS202.1, RV_TRI_BIAS201.1, RV_TRI_BIAS202.1, TH201.2, TH202.2, U201.3 (+), U201.5 (+), U202.3 (+), U204.3 (+), U204.5 (+), U205.3 (+), U207.5 (+), U208.3 (+), U208.5 (+), U209.3 (+), U209.5 (+), U210.5 (+), U211.3 (+), U211.5 (+), U212.3, U212.4, U212.7 (VSS), U212.11, U213.4 (V-), U215.6 (INH), U215.7 (VEE), U215.8 (VSS), U217.3 (+), U222.3 (+), U222.5 (+), U223.3 (+), U223.5 (+), U225.3 (+), U225.5 (+), U226.5 (+), U227.3 (+), U227.5 (+), U228.8 (VSS)
HEADPHONES: J204.5, R273.1, R274.1, TP229.1
KB_GATE: D207.2 (A), J203.9
KB_PITCH: J203.1, U218.3 (+)
LFO_A: J203.8, R294.1, TP230.1
LFO_A_RATE: J203.4, R278.1, R279.2
LFO_B: J203.6, R295.1, TP231.1
LFO_B_RATE: J203.2, R280.1, R281.2
MAIN_OUT: C276.2, J204.2, R231.1, R271.1, R272.2, TP227.1
MAIN_VOL_IN: C277.1, J204.3
MAIN_VOL_MAX: J204.1, RV_LINE_OUT_LVL201.2, TP228.1
NOISE: J214.1, R298.2, TP219.1, U222.1
NOISE_AUDIO: J214.5, RV202.3
unnamed: C207.2, R204.1, R_WIDTH201.2, R_WIDTH201.3, U201.1
unnamed: C208.2, R207.1, U201.7
unnamed: C217.2, R219.1, R_WIDTH202.2, R_WIDTH202.3, U204.1
unnamed: C218.2, R222.1, U204.7
unnamed: C225.1, RV201.2
unnamed: C225.2, R242.1
unnamed: C226.1, RV205.2
unnamed: C226.2, R243.1
unnamed: C227.1, RV202.2
unnamed: C227.2, R244.1
unnamed: C240.1, R267.1, TP221.1, U212.5
unnamed: C273.1, U202.7
unnamed: C274.1, U205.7
unnamed: C275.1, RV204.2
unnamed: C275.2, R338.1
unnamed: C282.2, R245.2, R246.1, U208.1
unnamed: C284.2, R234.2, R236.1, TP226.1, U207.7
unnamed: C228.1, D203.1 (K), D204.1 (K), R250.1, R252.2
unnamed: D205.2 (A), R257.1, R259.1, U210.2 (-)
unnamed: D205.1 (K), D206.1 (K)
unnamed: D207.1 (K), R264.2, U213.3 (+), U213.6 (-)
unnamed: C264.1, D212.1 (K), D213.1 (K), R304.1, R306.2
unnamed: D214.2 (A), R311.1, R313.1, U226.2 (-)
unnamed: D214.1 (K), D215.1 (K)
unnamed: C273.2, D216.1 (K), R328.1
unnamed: C274.2, D217.1 (K), R329.1
unnamed: C277.2, D_NEGATIVE_LIMITER201.1 (K), D_POSITIVE_LIMITER201.2 (A), R270.2, U217.5 (+)
unnamed: Q201.2 (B), R207.2
unnamed: Q201.1 (E), R209.2
unnamed: Q202.2 (B1), R204.2, R206.1, TP201.1
unnamed: C209.1, Q202.3 (C2), Q203.2 (S), Q211.2 (S), U202.2 (-)
unnamed: Q202.1 (E1), Q202.4 (E2), R209.1
unnamed: C210.2, Q203.3 (G), Q211.3 (G), R214.2, R215.1, TP204.1, U203.7
unnamed: Q204.2 (B), R222.2
unnamed: Q204.1 (E), R224.2
unnamed: Q205.2 (B1), R219.2, R221.1, TP205.1
unnamed: C219.1, Q205.3 (C2), Q206.2 (S), Q215.2 (S), U205.2 (-)
unnamed: Q205.1 (E1), Q205.4 (E2), R224.1
unnamed: C220.2, Q206.3 (G), Q215.3 (G), R229.2, R230.1, TP208.1, U206.7
unnamed: Q207.2 (B1), R232.2, R233.1, TP_VCA_AU_IN201.1
unnamed: Q207.6 (C1), R235.1, R238.1
unnamed: Q207.3 (C2), R237.1, R239.1
unnamed: Q207.1 (E1), Q207.4 (E2), R236.2, TP225.1
unnamed: Q208.2 (B), R288.2
unnamed: Q208.1 (C), R282.1, R284.2
unnamed: Q209.2 (B), R289.2
unnamed: Q209.1 (C), R283.1, R285.2
unnamed: Q210.2 (B), R297.1
unnamed: C257.2, Q210.3 (E), R296.2
unnamed: Q212.1 (B), R320.1
unnamed: Q212.3 (C), R321.2, U228.10 (CLK)
unnamed: Q213.1 (B), R328.2, R330.1
unnamed: Q213.3 (C), R212.1, R213.2, TP203.1, U203.3 (-)
unnamed: Q214.1 (B), R329.2, R331.1
unnamed: Q214.3 (C), R227.1, R228.2, TP207.1, U206.3 (-)
unnamed: R203.2, R_WIDTH201.1
unnamed: R206.2, TH201.1
unnamed: R210.2, R_HIFREQ201.2, R_HIFREQ201.3
unnamed: R218.2, R_WIDTH202.1
unnamed: R221.2, TH202.1
unnamed: R225.2, R_HIFREQ202.2, R_HIFREQ202.3
unnamed: R249.2, RV_SAW_BIAS201.2
unnamed: R253.2, RV_TRI_BIAS201.2
unnamed: R257.2, R262.2, TP215.1, U211.7
unnamed: R260.1, R261.2, U210.1
unnamed: R271.2, U217.7
unnamed: R272.1, RV_HEADPHONE_LIM201.3
unnamed: R277.2, U218.7
unnamed: R288.1, R292.2, U219.7
unnamed: R289.1, R293.2, U220.7
unnamed: R303.2, RV_SAW_BIAS202.2
unnamed: R307.2, RV_TRI_BIAS202.2
unnamed: R311.2, R316.2, TP216.1, U227.7
unnamed: R314.1, R315.2, U226.1
unnamed: R318.1, R_BIAS203.2
unnamed: R319.1, R_BIAS201.2
unnamed: R333.1, R334.2, R335.2
unnamed: R336.2, RV203.2
unnamed: RV_ADSR_MAX_VOLTAGE201.2, U212.9
unnamed: R324.2, R326.1, U202.6 (-)
unnamed: C210.1, R211.2, R214.1, U203.2 (+)
unnamed: U203.5 (BAL), U203.6 (STRB)
unnamed: R325.2, R327.1, U205.6 (-)
unnamed: C220.1, R226.2, R229.1, U206.2 (+)
unnamed: U206.5 (BAL), U206.6 (STRB)
unnamed: R239.2, R240.2, U207.3 (+)
unnamed: C285.1, R238.2, R241.1, TP_VCA_OUT202.1, U207.2 (-)
unnamed: C283.1, R246.2, R247.1, U208.6 (-)
unnamed: R248.1, R249.1, R251.2, U209.2 (-)
unnamed: R254.1, R255.2, U209.6 (-)
unnamed: R258.1, R260.2, U210.3 (+)
unnamed: C236.1, R261.1, R263.2, U210.6 (-)
unnamed: C235.2, R252.1, R253.1, R256.2, U211.2 (-)
unnamed: U212.1, U212.12
unnamed: U212.10, U213.7
unnamed: R265.2, R266.1, U213.2 (-), U213.5 (+)
unnamed: C241.1, U214.5 (+), U215.15 (B)
unnamed: R269.2, RV_ADSR_MAX_VOLTAGE201.1, TP_ADSR_OUT201.1, U214.6 (-), U214.7
unnamed: TP220.1, U215.2 (B0), U215.4 (C)
unnamed: R268.1, U215.1 (B1)
unnamed: TP222.1, U212.2, U212.13, U215.10 (S2)
unnamed: C240.2, TP223.1, U213.1, U215.9 (S3)
unnamed: RV_HEADPHONE_LIM201.2, U216.3 (+)
unnamed: R274.2, U216.1, U216.2 (-), U216.5 (+)
unnamed: R273.2, U216.6 (-), U216.7
unnamed: U217.1, U217.2 (-)
unnamed: C276.1, R231.2, U217.6 (-)
unnamed: R279.1, R286.1, U219.3 (+)
unnamed: C255.2, R278.2, R282.2, R284.1, U219.2 (-)
unnamed: R290.1, R292.1, U219.5 (+)
unnamed: R281.1, R287.1, U220.3 (+)
unnamed: C251.2, R280.2, R283.2, R285.1, U220.2 (-)
unnamed: R291.1, R293.1, U220.5 (+)
unnamed: R294.2, U221.1, U221.2 (-)
unnamed: R295.2, U221.6 (-), U221.7
unnamed: R297.2, R298.1, U222.2 (-)
unnamed: R335.1, R336.1, R337.2, U222.6 (-)
unnamed: R300.2, R301.1, U223.2 (-)
unnamed: U223.6 (-), U223.7
unnamed: R302.1, R303.1, R305.2, U225.2 (-)
unnamed: R308.1, R309.2, U225.6 (-)
unnamed: R312.1, R314.2, U226.3 (+)
unnamed: C272.1, R315.1, R317.2, U226.6 (-)
unnamed: C271.2, R306.1, R307.1, R310.2, U227.2 (-)
unnamed: R333.2, U228.9 (Q0)
unnamed: RV203.3, U228.7 (Q1)
unnamed: R332.1, U228.11 (Reset)
PITCH_BUFFERED: J203.3, U218.1, U218.2 (-)
RELEASE: J203.14, U215.5 (C0)
SUB: J214.3, R337.1, TP232.1, U222.7
SUBMIX: C283.2, J204.15, R247.2, TP224.1, U208.7
SUB_AUDIO: J214.7, RV204.3
SUSTAIN: J203.11, U214.3 (+)
VCA_AUDIO_IN: J204.9, R232.1, TP_VCA_AU_IN202.1
VCA_ENV_CV: C284.1, J204.7, R234.1, U207.6 (-)
VCO1_AUDIO: J202.1, RV201.3
VCO1_CV: C217.1, J202.11, R216.2, R217.1, R218.1, R319.2, U204.2 (-)
VCO1_FM: J202.13, R220.1
VCO1_SAW: D212.2 (A), J201.3, R309.1, R312.2, TP212.1, U225.7
VCO1_SQR: C272.2, J201.7, R317.1, TP218.1, U226.7
VCO1_SQR_SHAPE: J201.5, R316.1, U227.6 (-)
VCO1_SYNC: J202.15, R323.1, U205.5 (+)
VCO1_TRI: C271.1, J201.1, R310.1, TP214.1, U227.1
VCO2_AUDIO: J202.3, RV205.3
VCO2_CV: C207.1, J202.5, R201.2, R202.1, R203.1, R318.2, U201.2 (-)
VCO2_FM: J202.7, R205.1
VCO2_SAW: D203.2 (A), J201.11, R255.1, R258.2, TP211.1, U209.7
VCO2_SQR: C236.2, J201.15, R263.1, TP217.1, U210.7
VCO2_SQR_SHAPE: J201.13, R262.1, U211.6 (-)
VCO2_SYNC: J202.9, R322.1, U202.5 (+)
VCO2_TRI: C235.1, J201.9, R256.1, TP213.1, U211.1

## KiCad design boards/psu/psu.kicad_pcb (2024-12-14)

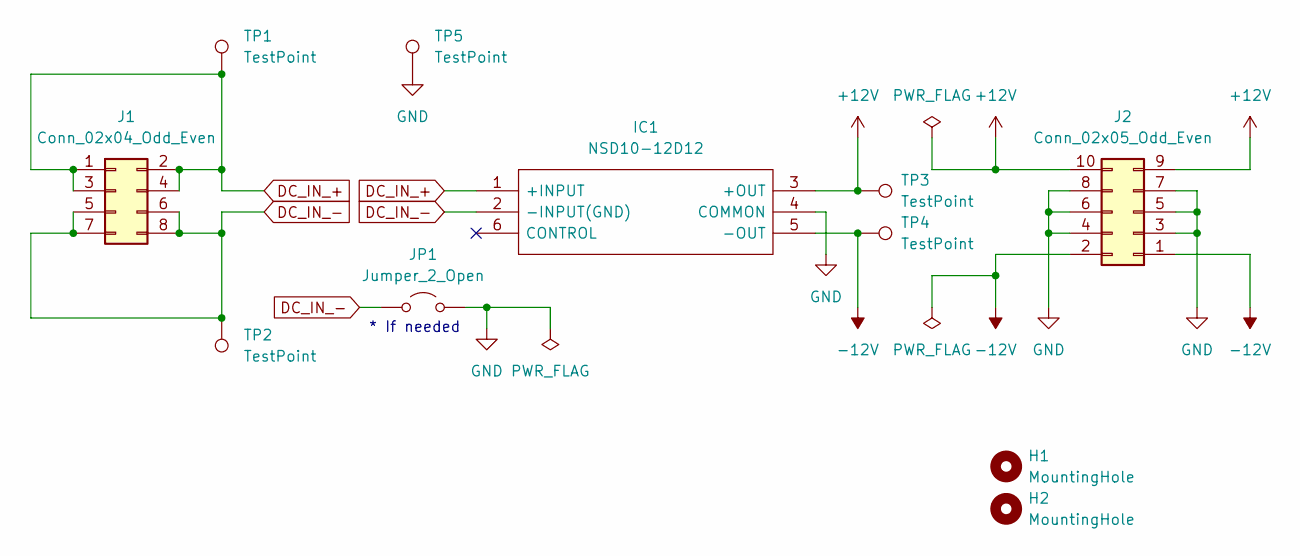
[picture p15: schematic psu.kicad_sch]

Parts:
H1, H2: MountingHole; MountingHole_3mm_Pad; Part No. N/A
IC1: NSD10-12D12; NSD1012D5; Manufacturer_Part_Number NSD10-12D12; Mouser Part Number 709-NSD10-12D5
J1: Conn_02x04_Odd_Even; PinSocket_2x04_P2.54mm_Vertical; Part No. 737-RS2-08-G
J2: Conn_02x05_Odd_Even; PinSocket_2x05_P2.54mm_Vertical; Part No. 737-RS2-10-G
JP1: Jumper_2_Open; SolderJumper-2_P1.3mm_Open_Pad1.0x1.5mm; Part No. N/A
TP1, TP2, TP3, TP4, TP5: TestPoint; TestPoint_THTPad_2.0x2.0mm_Drill1.0mm; Part No. N/A

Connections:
+12V: IC1.3 (+OUT), J2.9, J2.10, TP3.1
-12V: IC1.5 (-OUT), J2.1, J2.2, TP4.1
DC_IN_+: IC1.1 (+INPUT), J1.1, J1.2, J1.3, J1.4, TP1.1
DC_IN_-: IC1.2 (-INPUT(GND)), J1.5, J1.6, J1.7, J1.8, JP1.1 (A), TP2.1
GND: IC1.4 (COMMON), J2.3, J2.4, J2.5, J2.6, J2.7, J2.8, JP1.2 (B), TP5.1

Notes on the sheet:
* If needed

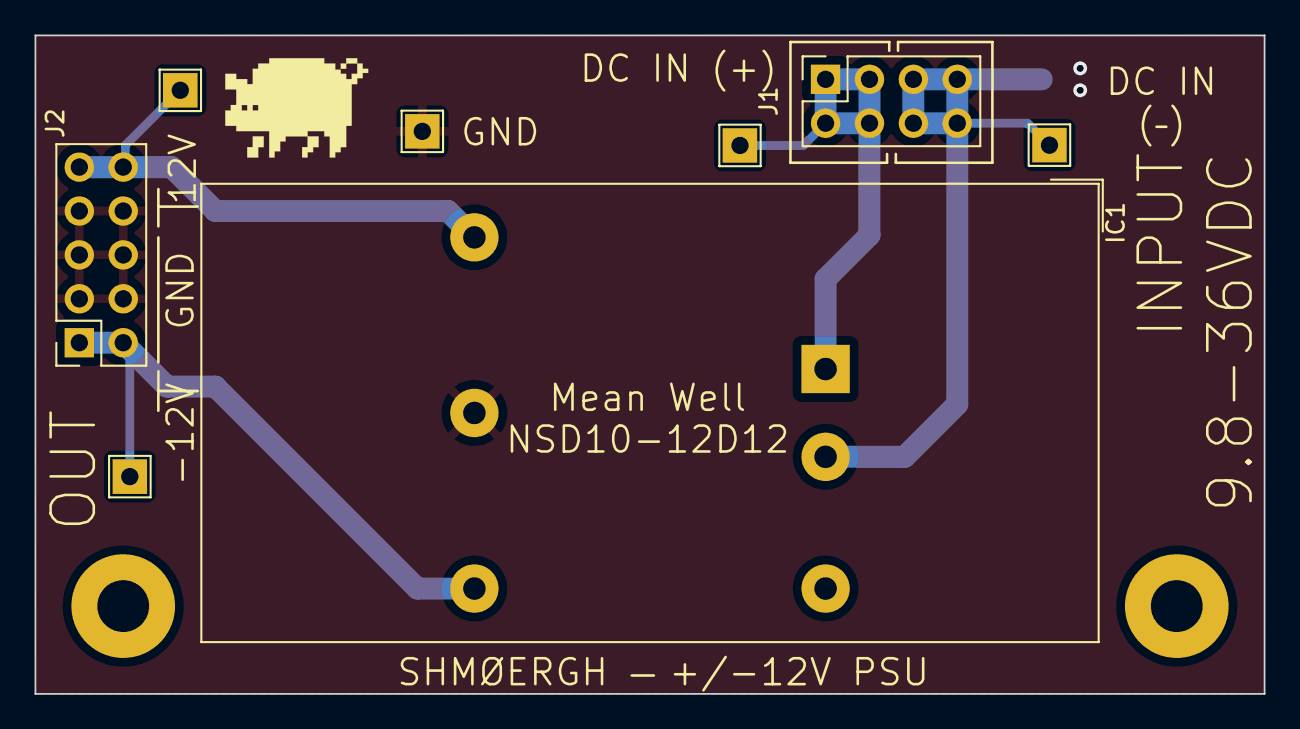
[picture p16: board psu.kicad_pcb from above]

Board: 2 copper layers, 71.1 x 38.1 mm, 11 parts (1 on the bottom side), 5 nets.

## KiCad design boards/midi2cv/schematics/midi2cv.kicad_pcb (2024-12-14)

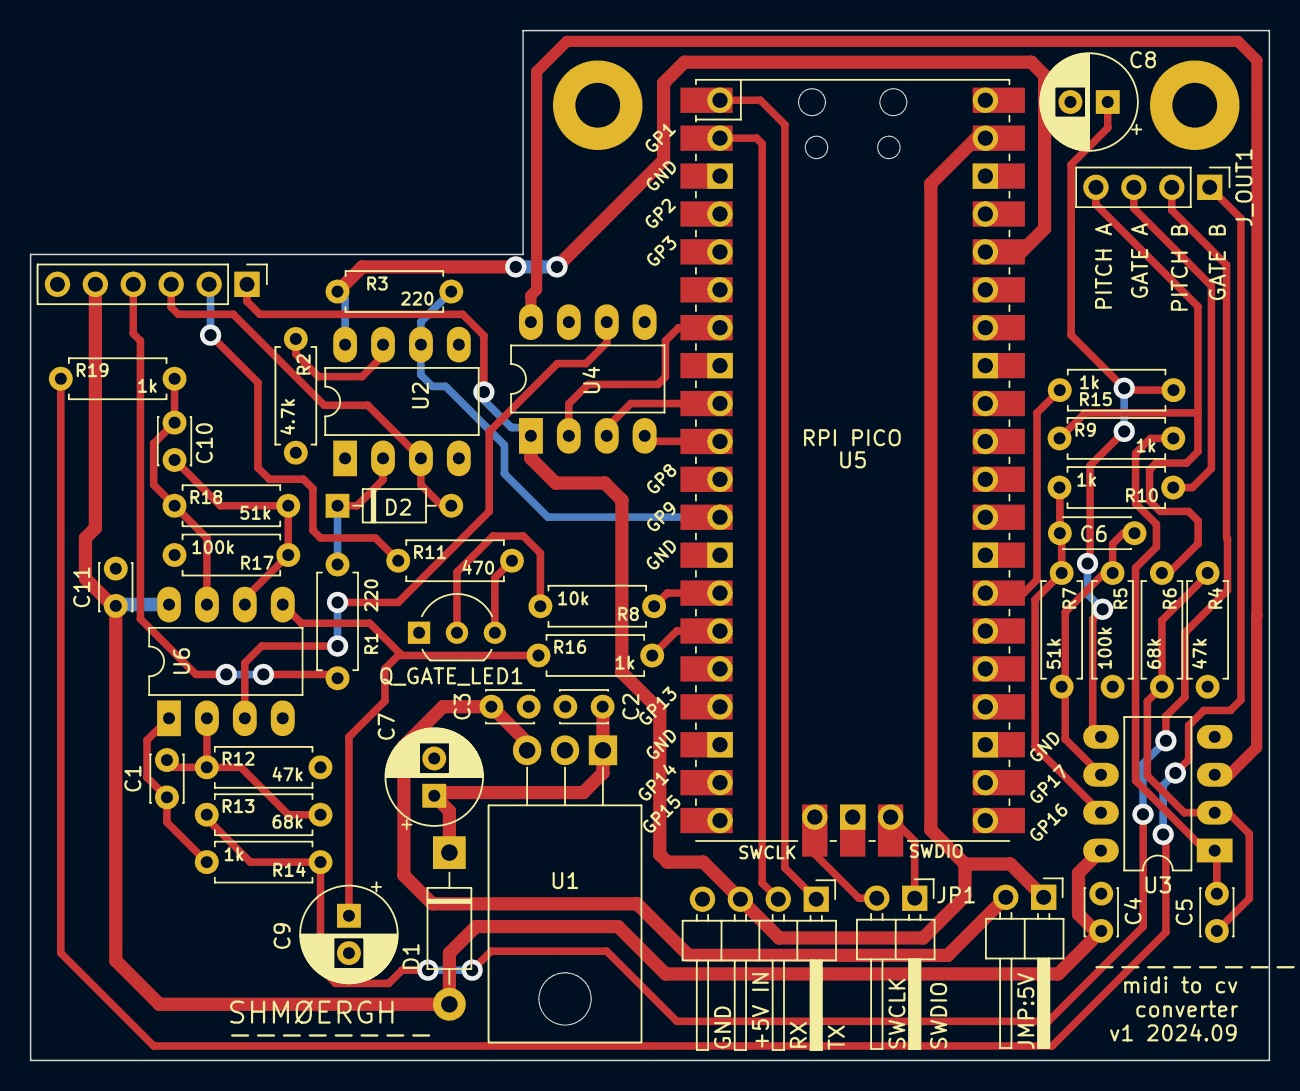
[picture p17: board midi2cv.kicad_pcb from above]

Board: 2 copper layers, 83.0 x 69.0 mm, 46 parts (0 on the bottom side), 40 nets.

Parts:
C1, C5, C10: 22p; C_Disc_D3.0mm_W2.0mm_P2.50mm
C2: 330n; C_Disc_D3.0mm_W2.0mm_P2.50mm
C3, C4, C11: 100n; C_Disc_D3.0mm_W2.0mm_P2.50mm
C6: 22p; C_Disc_D4.3mm_W1.9mm_P5.00mm
C7: 10u; CP_Radial_D6.3mm_P2.50mm
C8, C9: 1u; CP_Radial_D6.3mm_P2.50mm
D1: 1N4001; D_DO-41_SOD81_P10.16mm_Horizontal
D2: 1N4148; D_DO-35_SOD27_P7.62mm_Horizontal
H1, H2: MountingHole; MountingHole_3mm_Pad
JP1: Jumper_2_Open; PinHeader_1x02_P2.54mm_Horizontal
J_IN1: Conn_01x06; PinHeader_1x06_P2.54mm_Vertical
J_OUT1: Conn_01x04; PinHeader_1x04_P2.54mm_Vertical
J_SWCLKDIO1: Conn_01x02; PinHeader_1x02_P2.54mm_Horizontal
J_SWD_IO1: Conn_01x04; PinHeader_1x04_P2.54mm_Horizontal
Q_GATE_LED1: 2N3904; TO-92_Inline_Wide
R1, R3: 220; R_Axial_DIN0207_L6.3mm_D2.5mm_P7.62mm_Horizontal
R2: 4.7k; R_Axial_DIN0207_L6.3mm_D2.5mm_P7.62mm_Horizontal
R4, R12: 47k; R_Axial_DIN0207_L6.3mm_D2.5mm_P7.62mm_Horizontal
R5, R17: 100k; R_Axial_DIN0207_L6.3mm_D2.5mm_P7.62mm_Horizontal
R6, R13: 68k; R_Axial_DIN0207_L6.3mm_D2.5mm_P7.62mm_Horizontal
R7, R18: 51k; R_Axial_DIN0207_L6.3mm_D2.5mm_P7.62mm_Horizontal
R8: 10k; R_Axial_DIN0207_L6.3mm_D2.5mm_P7.62mm_Horizontal
R9, R10, R14, R15, R16, R19: 1k; R_Axial_DIN0207_L6.3mm_D2.5mm_P7.62mm_Horizontal
R11: 470; R_Axial_DIN0207_L6.3mm_D2.5mm_P7.62mm_Horizontal
U1: LM7805_TO220; TO-220-3_Horizontal_TabDown
U2: 6N138; DIP-8_W7.62mm_LongPads
U3, U6: LM358; DIP-8_W7.62mm_LongPads
U4: MCP4822; DIP-8_W7.62mm_LongPads
U5: Pico; RPi_Pico_SMD_TH

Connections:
+3.3V: R3.1, U2.8 (VCC), U5.36 (3V3)
+5V: JP1.1 (A), J_IN1.1, J_SWD_IO1.3, U4.1 (Vdd), U5.39 (VSYS)
+12V: C4.1, C11.1, D1.2 (A), J_IN1.5, U3.8 (V+), U6.8 (V+)
DAC_A: U3.3 (+), U4.8 (VA)
DAC_B: U4.6 (VB), U6.3 (+)
DAC_CS: U4.2 (~CS), U5.7 (GPIO5)
DAC_SCK: U4.3 (SCK), U5.9 (GPIO6)
DAC_SDI: U4.4 (SDI), U5.10 (GPIO7)
GATE_A: J_OUT1.3, R10.1
GATE_A_TRIG: R15.2, U5.27 (GPIO21)
GATE_B: J_OUT1.1, R19.1
GATE_B_TRIG: R16.2, U5.15 (GPIO11)
GND: C2.2, C3.2, C4.2, C7.2, C8.2, C9.2, C11.2, J_IN1.6, J_SWD_IO1.4, Q_GATE_LED1.1 (E), R2.2, R4.2, R5.2, R12.2, R17.2, U1.2 (GND), U2.5 (GND), U3.4 (V-), U4.5 (~LDAC), U4.7 (Vss), U5.3 (GND), U5.8 (GND), U5.13 (GND), U5.18 (GND), U5.23 (GND), U5.28 (GND), U5.38 (GND), U6.4 (V-)
LED_GND: J_IN1.2, R11.1
LED_OUT: R8.1, U5.14 (GPIO10)
MIDI_4R: J_IN1.4, R1.2
MIDI_5T: D2.2 (A), J_IN1.3, U2.3 (C2)
MIDI_IN: R3.2, U2.6 (VO2), U5.12 (GPIO9)
unnamed: C1.1, R14.2, U6.1
unnamed: C5.1, R9.2, U3.1
unnamed: C6.1, R7.1, R10.2, U3.7
unnamed: C10.1, R18.1, R19.2, U6.7
unnamed: C2.1, C7.1, D1.1 (K), U1.1 (VI)
unnamed: D2.1 (K), R1.1, U2.2 (C1)
unnamed: C3.1, JP1.2 (B), U1.3 (VO)
unnamed: J_SWCLKDIO1.1, U5.43 (SWDIO)
unnamed: J_SWCLKDIO1.2, U5.41 (SWCLK)
unnamed: Q_GATE_LED1.2 (B), R8.2
unnamed: Q_GATE_LED1.3 (C), R11.2
unnamed: R2.1, U2.7 (VO1)
unnamed: C5.2, R4.1, R6.2, U3.2 (-)
unnamed: C8.1, R15.1, U3.5 (+)
unnamed: C6.2, R5.1, R7.2, U3.6 (-)
unnamed: C1.2, R12.1, R13.2, U6.2 (-)
unnamed: C9.1, R16.1, U6.5 (+)
unnamed: C10.2, R17.1, R18.2, U6.6 (-)
PITCH_A: J_OUT1.4, R6.1, R9.1
PITCH_B: J_OUT1.2, R13.1, R14.1
UART_RX: J_SWD_IO1.2, U5.2 (GPIO1)
UART_TX: J_SWD_IO1.1, U5.1 (GPIO0)

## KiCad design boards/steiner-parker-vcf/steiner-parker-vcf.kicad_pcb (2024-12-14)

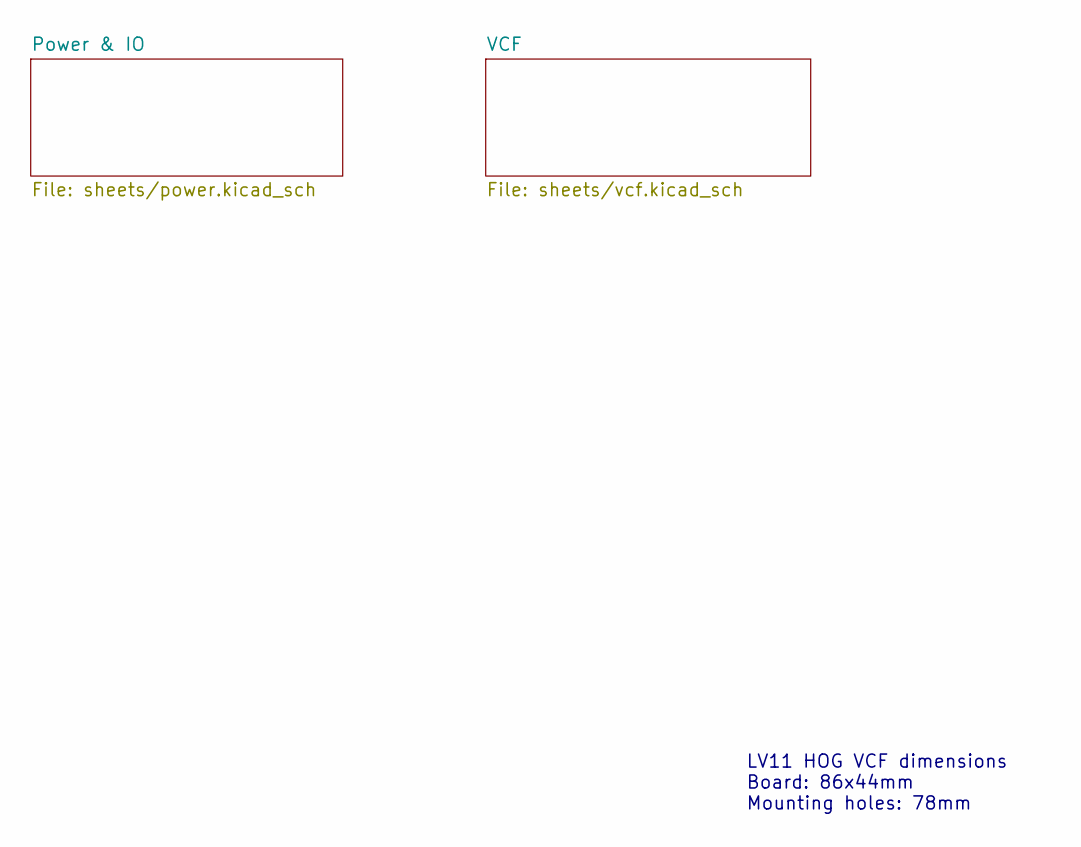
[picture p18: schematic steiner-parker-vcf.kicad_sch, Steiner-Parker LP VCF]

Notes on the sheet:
LV11 HOG VCF dimensions Board: 86x44mm Mounting holes: 78mm

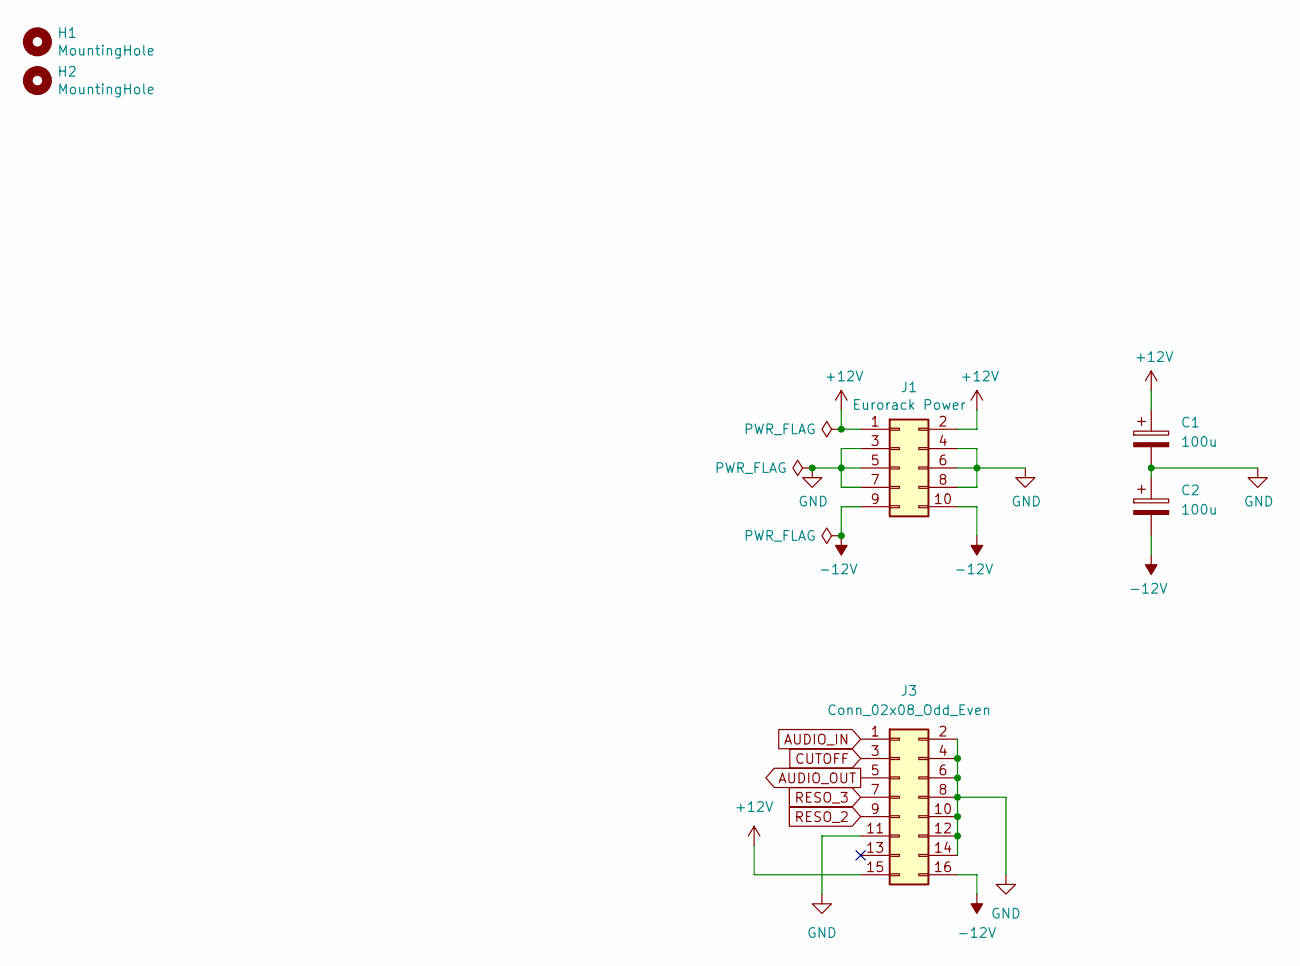
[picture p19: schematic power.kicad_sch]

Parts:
C1, C2: 100u; CP_Elec_6.3x7.7; LCSC C2836437
H1, H2: MountingHole; MountingHole_3mm_Pad
J1: Eurorack Power; PinHeader_2x05_P2.54mm_Vertical; Part No. 737-RS2-10-G
J3: Conn_02x08_Odd_Even; PinHeader_2x08_P2.54mm_Vertical; Part No. 737-RS2-16-G

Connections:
+12V: C1.1, J1.1, J1.2, J3.15; also elsewhere on the board
-12V: C2.2, J1.9, J1.10, J3.16; also elsewhere on the board
AUDIO_IN: J3.1; also elsewhere on the board
AUDIO_OUT: J3.5; also elsewhere on the board
CUTOFF: J3.3; also elsewhere on the board

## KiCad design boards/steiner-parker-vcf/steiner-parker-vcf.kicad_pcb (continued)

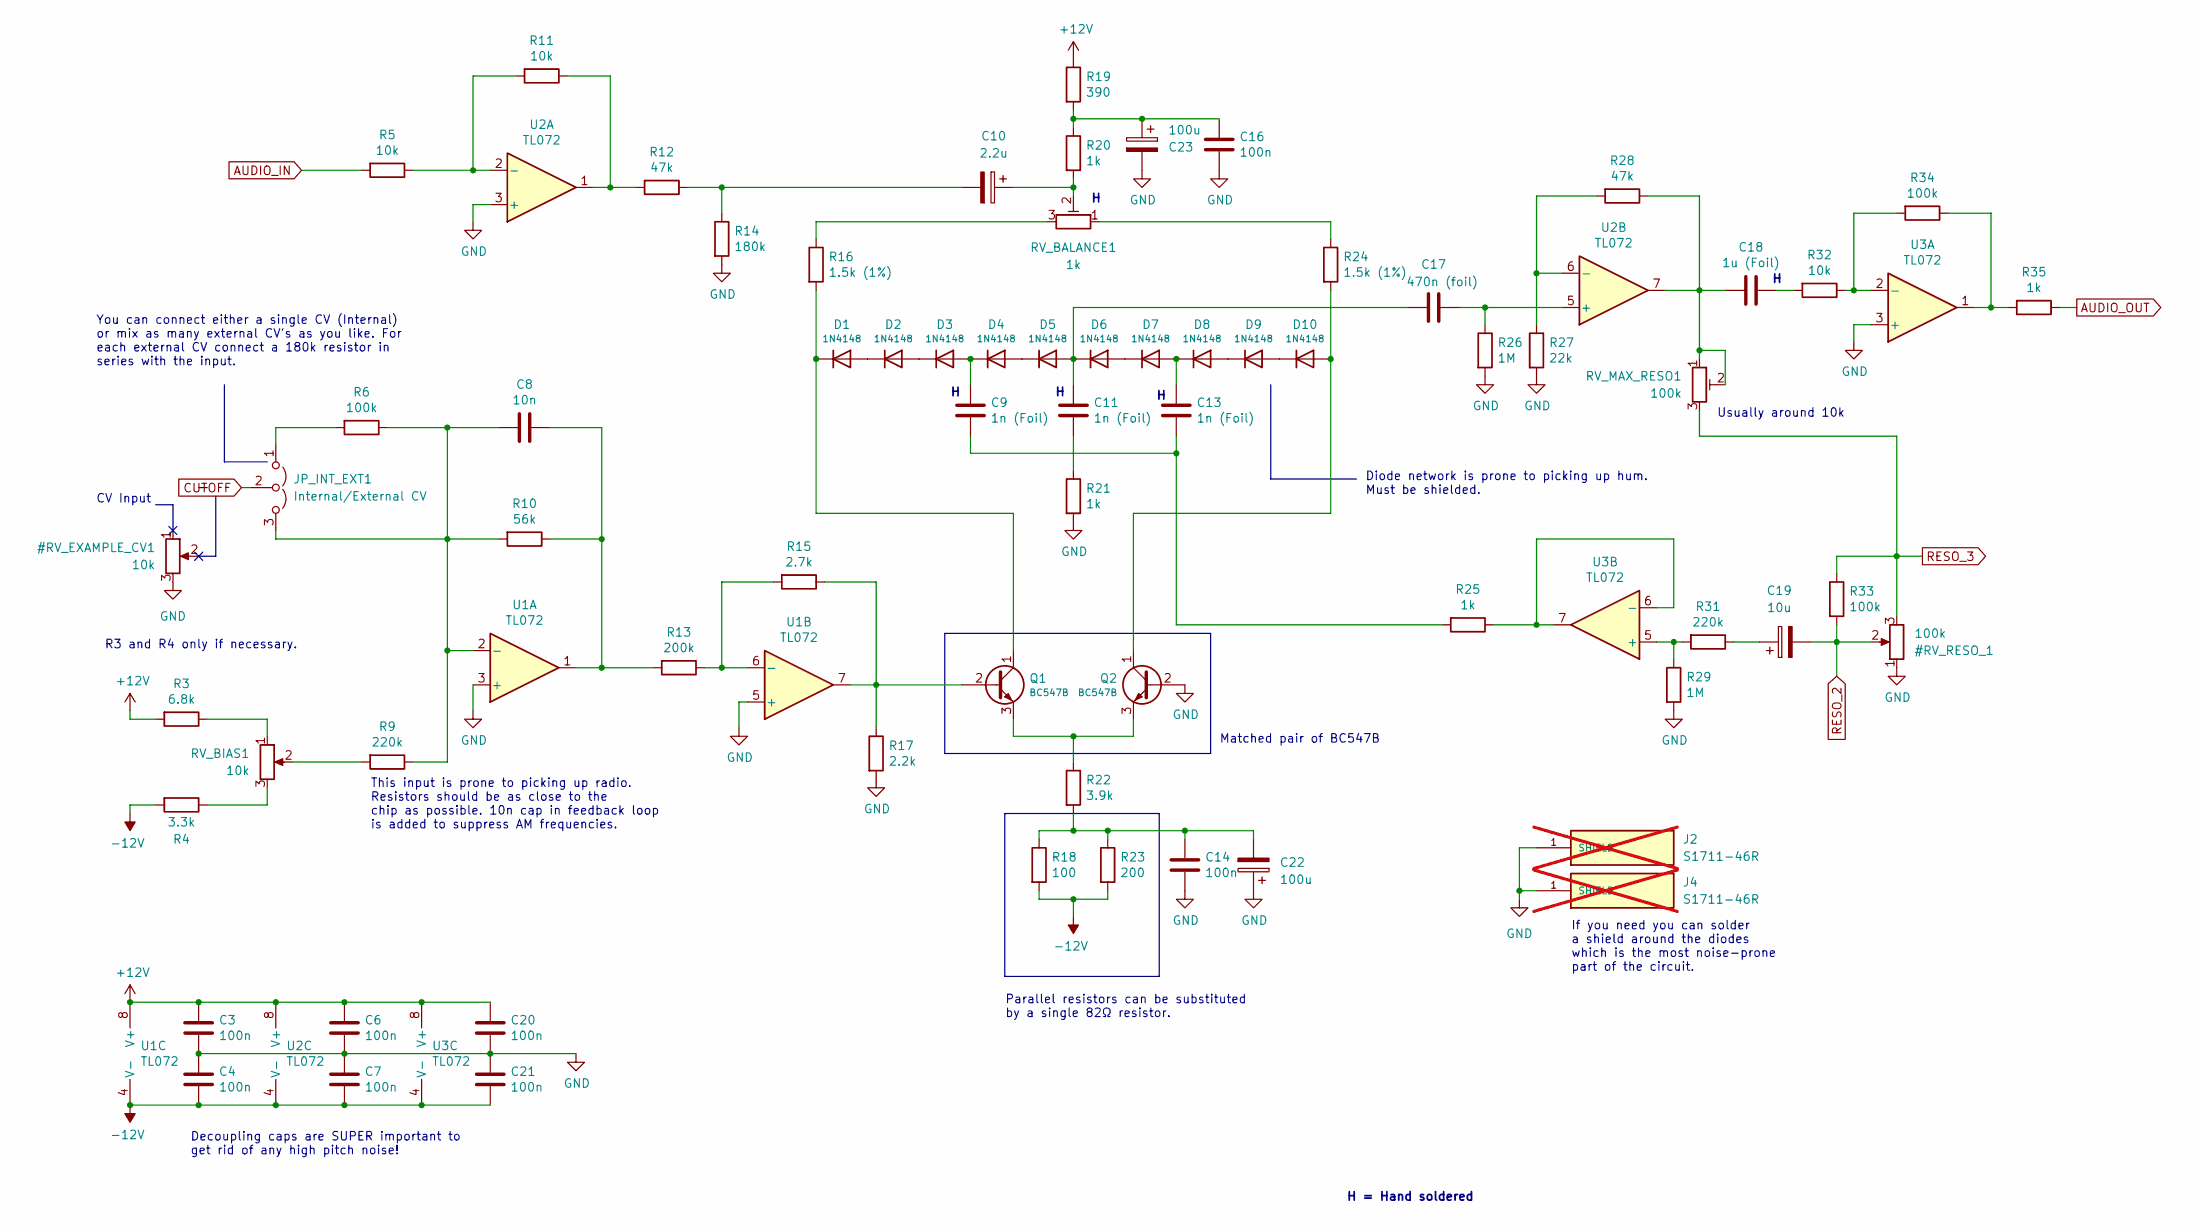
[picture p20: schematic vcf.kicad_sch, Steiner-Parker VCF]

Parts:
C3, C4, C6, C7, C14, C16, C20, C21: 100n; C_0603_1608Metric_Pad1.08x0.95mm_HandSolder; LCSC C14663
C8: 10n; C_0603_1608Metric_Pad1.08x0.95mm_HandSolder; LCSC C57112
C9, C11, C13: 1n (Foil); C_Rect_L7.0mm_W2.5mm_P5.00mm; Part No. 80-R82EC1100SH50J
C10: 2.2u; CP_Elec_4x5.4; LCSC C43242
C17: 470n (foil); C_Rect_L7.0mm_W3.5mm_P5.00mm; Part No. 80-R82EC1470DQ50K
C18: 1u (Foil); C_Rect_L7.0mm_W4.5mm_P5.00mm; Part No. 80-R82EC4100Z370K
C19: 10u; CP_Elec_4x5.4; LCSC C3343
C22, C23: 100u; CP_Elec_6.3x7.7; LCSC C2836437
D1, D2, D3, D4, D5, D6, D7, D8, D9, D10: 1N4148; D_SOD-123; LCSC C81598
J2, J4: S1711-46R; HARWIN_S1711-46R; PARTREV 23/10/18; not fitted
JP_INT_EXT1: Internal/External CV; PinSocket_1x03_P2.54mm_Vertical; Part No. 737-PH1-20-UA
Q1, Q2: BC547B; TO-92_Inline_Wide; Part No. 637-BC547B
R3: 6.8k; R_Axial_DIN0207_L6.3mm_D2.5mm_P7.62mm_Horizontal; Part No. 303-MF0W4FF6801B00
R4: 3.3k; R_Axial_DIN0207_L6.3mm_D2.5mm_P7.62mm_Horizontal; Part No. 303-CFR0W4J0332B00
R5, R11, R32: 10k; R_0603_1608Metric_Pad0.98x0.95mm_HandSolder; LCSC C25804
R6, R33, R34: 100k; R_0603_1608Metric_Pad0.98x0.95mm_HandSolder; LCSC C25803
R9, R31: 220k; R_0603_1608Metric_Pad0.98x0.95mm_HandSolder; LCSC C22961
R10: 56k; R_0603_1608Metric_Pad0.98x0.95mm_HandSolder; LCSC C23206
R12, R28: 47k; R_0603_1608Metric_Pad0.98x0.95mm_HandSolder; LCSC C25819
R13: 200k; R_0603_1608Metric_Pad0.98x0.95mm_HandSolder; LCSC C25811
R14: 180k; R_0603_1608Metric_Pad0.98x0.95mm_HandSolder; LCSC C3016400
R15: 2.7k; R_0603_1608Metric_Pad0.98x0.95mm_HandSolder; LCSC C13167
R16, R24: 1.5k (1%); R_0603_1608Metric_Pad0.98x0.95mm_HandSolder; LCSC C22843
R17: 2.2k; R_0603_1608Metric_Pad0.98x0.95mm_HandSolder; LCSC C4190
R18: 100; R_0603_1608Metric_Pad0.98x0.95mm_HandSolder; LCSC C22775
R19: 390; R_0603_1608Metric_Pad0.98x0.95mm_HandSolder; LCSC C23151
R20, R21, R25, R35: 1k; R_0603_1608Metric_Pad0.98x0.95mm_HandSolder; LCSC C21190
R22: 3.9k; R_0603_1608Metric_Pad0.98x0.95mm_HandSolder; LCSC C23018
R23: 200; R_0603_1608Metric_Pad0.98x0.95mm_HandSolder; LCSC C8218
R26, R29: 1M; R_0603_1608Metric_Pad0.98x0.95mm_HandSolder; LCSC C22935
R27: 22k; R_0603_1608Metric_Pad0.98x0.95mm_HandSolder; LCSC C31850
RV_BALANCE1: 1k; Potentiometer_ACP_CA6-H2,5_Horizontal; Part No. 531-PT6KH-1K
RV_BIAS1: 10k; Potentiometer_ACP_CA6-H2,5_Horizontal; Part No. 531-PT6KH-10K
RV_MAX_RESO1: 100k; Potentiometer_ACP_CA6-H2,5_Horizontal; Part No. 531-PT6KH104A1010PM
U1, U2, U3: TL072; SOIC-8_3.9x4.9mm_P1.27mm; LCSC C6961

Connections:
+12V: C3.1, C6.1, C20.1, R3.2, R19.1, U1.8 (V+), U2.8 (V+), U3.8 (V+); also elsewhere on the board
-12V: C4.2, C7.2, C21.2, R4.2, R18.2, R23.2, U1.4 (V-), U2.4 (V-), U3.4 (V-); also elsewhere on the board
AUDIO_IN: R5.2; also elsewhere on the board
AUDIO_OUT: R35.1; also elsewhere on the board
CUTOFF: JP_INT_EXT1.2 (C); also elsewhere on the board
unnamed: C8.1, R10.1, R13.2, U1.1
unnamed: C10.1, R20.2, RV_BALANCE1.2
unnamed: C10.2, R12.1, R14.1
unnamed: C11.2, R21.1
unnamed: C9.2, C13.2, R25.2
unnamed: C14.1, C22.2, R18.1, R22.2, R23.1
unnamed: C16.1, C23.1, R19.2, R20.1
unnamed: C18.1, R32.2
unnamed: C18.2, R28.1, RV_MAX_RESO1.1, RV_MAX_RESO1.2, U2.7
unnamed: C19.1, R31.1
unnamed: D1.2 (A), D2.1 (K)
unnamed: D1.1 (K), Q1.1 (C), R16.2
unnamed: D2.2 (A), D3.1 (K)
unnamed: C9.1, D3.2 (A), D4.1 (K)
unnamed: D4.2 (A), D5.1 (K)
unnamed: C11.1, C17.2, D5.2 (A), D6.1 (K)
unnamed: D6.2 (A), D7.1 (K)
unnamed: C13.1, D7.2 (A), D8.1 (K)
unnamed: D8.2 (A), D9.1 (K)
unnamed: D10.2 (A), Q2.1 (C), R24.2
unnamed: D9.2 (A), D10.1 (K)
unnamed: JP_INT_EXT1.1 (A), R6.2
unnamed: C8.2, JP_INT_EXT1.3 (B), R6.1, R9.1, R10.2, U1.2 (-)
unnamed: Q1.2 (B), R15.1, R17.1, U1.7
unnamed: Q1.3 (E), Q2.3 (E), R22.1
unnamed: R3.1, RV_BIAS1.1
unnamed: R4.1, RV_BIAS1.3
unnamed: R9.2, RV_BIAS1.2
unnamed: R11.1, R12.2, U2.1
unnamed: R16.1, RV_BALANCE1.3
unnamed: R24.1, RV_BALANCE1.1
unnamed: R34.1, R35.2, U3.1
unnamed: R13.1, R15.2, U1.6 (-)
unnamed: R5.1, R11.2, U2.2 (-)
unnamed: C17.1, R26.1, U2.5 (+)
unnamed: R27.1, R28.2, U2.6 (-)
unnamed: R32.1, R34.2, U3.2 (-)
unnamed: R29.1, R31.2, U3.5 (+)
unnamed: R25.1, U3.6 (-), U3.7

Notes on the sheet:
CV Input
H = Hand soldered
This input is prone to picking up radio. Resistors should be as close to the chip as possible. 10n cap in feedback loop is added to suppress AM frequencies.
If you need you can solder a shield around the diodes which is the most noise-prone part of the circuit.
Decoupling caps are SUPER important to get rid of any high pitch noise!
Matched pair of BC547B
R3 and R4 only if necessary.
Parallel resistors can be substituted by a single 82Ω resistor.
Usually around 10k
You can connect either a single CV (Internal) or mix as many external CV's as you like. For each external CV connect a 180k resistor in series with the input.
Diode network is prone to picking up hum. Must be shielded.

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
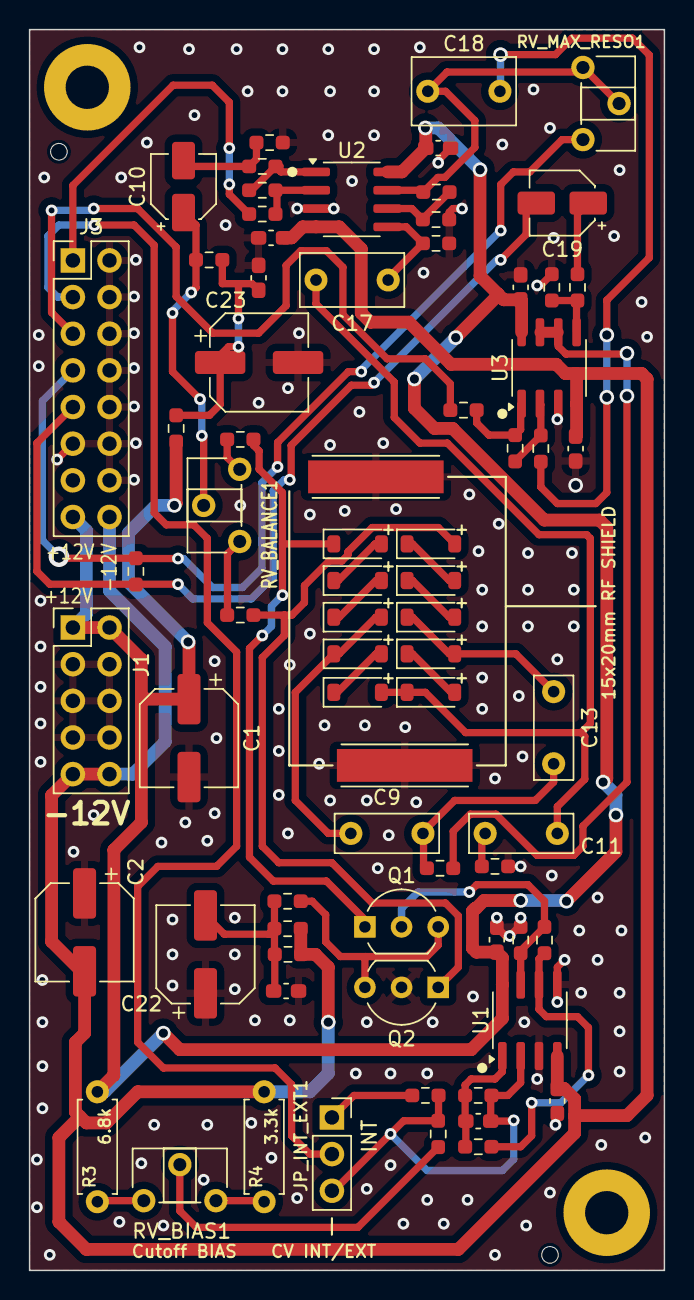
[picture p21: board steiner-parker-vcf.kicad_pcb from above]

Board: 2 copper layers, 44.0 x 86.0 mm, 75 parts (0 on the bottom side), 47 nets.

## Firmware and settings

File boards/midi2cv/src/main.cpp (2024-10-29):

/**
 * @author Peter Zimon / Shmøergh (shmoergh.com)
 * @copyright Copyright (c) 2024
 *
 * Building blocks (classes)
 * -------------------------
 * MidiHandler
 * - Sets up uart for incoming MIDI
 * - Parses MIDI using midi_parser library
 * - Saves notes in a note stack for last-note-priority output
 *
 * MidiToCV
 * - Looks up the MIDI channel setting. Note that MIDI channel setting is only
 *   scanned at boot. If you change the MIDI channel then you have to reboot
 *   the system.
 * - Sets dac CV voltage based on the midi_handler note stack
 * - Sets gate gpio
 * - Saves settings for MIDI to CV conversion (if there's any)
 *
 * UI
 * - Handles gpio for UI
 *
 * Connections
 * -----------
 * midi_to_cv.attach(midi_handler)
 * midi_to_cv.attach(dac)
 * midi_to_cv.attach(ui)
 *
 * Flashing
 * --------
 * DISCONNECT FROM POWER BEFORE FLASHING!!!!
 */

/*
 * C++ headers
 */
#include <iostream>
#include <string>
#include <vector>
#include <cstdlib>
#include <cstdint>
#include <cstring>

/*
 * Pico headers
 */
#include "pico/stdlib.h"
#include "pico/binary_info.h"
#include "hardware/gpio.h"
#include "hardware/spi.h"
#include "hardware/adc.h"
#include "hardware/uart.h"
#include "hardware/flash.h"
#include "hardware/sync.h"

/*
 * Custom libraries
 */
#include <mcp48x2.h>

/*
 * Project headers
 */
#include "settings.h"
#include "midi_handler.h"
#include "ui.h"
#include "midi_to_cv.h"

Settings settings;
MCP48X2 dac;
MidiHandler midi_handler;
UI ui;
MidiToCV midi_to_cv;

int main() {
    stdio_init_all();

    sleep_ms(500);

    printf("-------------------\r\n");
    printf("Let's do this shit!\r\n");

    ui.init();
    dac.init(DAC_SPI_PORT, GP_DAC_CS, GP_DAC_SCK, GP_DAC_MOSI);
    midi_handler.init();
    midi_to_cv.init();
    settings.init();

    midi_to_cv.attach(&midi_handler);
    midi_to_cv.attach(&dac);
    midi_to_cv.attach(&ui);
    midi_to_cv.attach(&settings);

    while (1) {
        ui.update();
        midi_to_cv.process();
    }

    return 0;
}

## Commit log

2024-10-29 Rev 3
    [adsr-logic.kicad_sch, adsr.kicad_sch, buffers.kicad_sch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]
2024-11-10 Folder restructure
    [adsr-logic.kicad_sch, adsr.kicad_sch, buffers.kicad_sch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]
2024-11-10 Added schematics docs
    [adsr.kicad_sch, buffers.kicad_sch, filter_ui.kicad_sch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]
2024-11-23 Added LFO LED resistor values
    https://github.com/shmoergh/hog/issues/24
    [lfo_ui.kicad_sch]
2024-11-23 Updated MIDI IO
    UI: Set default pin of PITCH and GATE inputs to MIDI converter's respective outputs
    UI: Add 12V power for MIDI2CV converter connector
    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
    [io.kicad_sch]
2024-11-23 Updated RESO pot resistance value
    ref. https://github.com/shmoergh/hog/issues/24
    UI: Update dirty dual pot to 50kΩ (100kΩ is not available at Mouser)
    [filter_ui.kicad_sch]
2024-11-23 Updated minimum Cutoff resistance on filter
    Filter: update R4 value to 3.3kΩ. This allows better minimum cutoff value
    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
    [steiner-parker-vcf.kicad_pcb, vcf.kicad_sch]
2024-11-23 Removed VCA rejection trimpot
    https://github.com/shmoergh/hog/issues/8
    Also updated Core board footprints to work with fcking KiCad 8
    [core.kicad_pcb, vca.kicad_sch]
2024-11-23 Replaced mixer feedback resistor to SMD
    https://github.com/shmoergh/hog/issues/9
    [mixer.kicad_sch]
2024-11-23 Replaced mixer input caps to SMD
    https://github.com/shmoergh/hog/issues/26
    [core.kicad_pcb, mixer.kicad_sch]
2024-11-23 Added THT footprint to J111 in VCOs
    https://github.com/shmoergh/hog/issues/10
    [core.kicad_pcb, vco.kicad_sch]
2024-11-23 Separate Core board to versions
    https://github.com/shmoergh/hog/issues/7
    - Removed precision +/-5V circuit and its outputs as it's unnecessary for the Core board
    [adsr.kicad_sch, buffers.kicad_sch, core.kicad_pcb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]
2024-11-24 Streamline 'Stable' Core board
    - Remove 12V terminal input
    - Reposition Eurorack power connector to right so it makes space for tuning
    - Remove all unnecessary thermal compensation pseudo components
    - Reposition tuning trimmers
    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
    [core.kicad_pcb, core.kicad_sch, power.kicad_sch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]
2024-11-30 Repositioned connectors on Core board
    ref https://github.com/shmoergh/hog/issues/30
    Connectors have to be aligned on the 1mm grid on the Core board so that it's easy to align the connector pairs on the UI board.
    [core.kicad_pcb]
2024-11-30 Updated UI board connector positions
    https://github.com/shmoergh/hog/issues/31
    Moving the tuner trimmers on the Core board required to reposition the connector headers too. This also had to be done on the UI board otherwise it won't be possible to connect the two boards.
    [core.kicad_pcb, core.kicad_sch, power.kicad_sch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]
2024-11-30 Added FAB drawings of all boards for UI
    As a preparation for making everything more streamlined
    [power.kicad_sch]
2024-12-01 Replaced wired MIDI connection to pins
    https://github.com/shmoergh/hog/issues/32
    MIDI connection was done with manual wired NTS connectors. Now they are replaced with pins and pinheaders just like the other boards.
    [io.kicad_sch, main_vol_ui.kicad_sch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]
2024-12-08 Created PSU board
    https://github.com/shmoergh/hog/issues/4
    [psu.kicad_pcb, psu.kicad_sch]
2024-12-09 Created BOM for PSU board
    ref https://github.com/shmoergh/hog/issues/19
    [psu-bom.csv, psu.kicad_sch]
2024-12-09 Removed backpanel IO conn. + fixed drone voltage
    https://github.com/shmoergh/hog/issues/37
    The IO back panel connector on the UI board is a leftover from an earlier prototype. Can be removed.
    https://github.com/shmoergh/hog/issues/36
    ATM the gate voltage for drone mode is fixed to 5V which makes it quieter than the normal gate. Drone mode gate voltage should be 8V.
    [adsr-logic.kicad_sch, ui.kicad_sch]
2024-12-13 Updated and checked Core board BOM
    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
    [adsr.kicad_sch, buffers.kicad_sch, core.kicad_pcb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]
2024-12-14 Added JLCPCB production files to Core
    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
    [bom.csv, core.kicad_pcb, designators.csv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]
2024-12-14 Added Core full BOM
    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
    [CORE-FULL-BOM.csv]
2024-12-14 Added Core Mouser BOM csv and Production readme
    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
    [adsr.kicad_sch, bom.csv, core-full-bom.csv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]
2024-12-14 Added BOM and gerber for PSU board
    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
    [psu-bom-mouser.csv, psu-bom.csv]
2024-12-14 Added production files for VCF
    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
    [bom.csv, designators.csv, positions.csv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]
2024-12-14 Added production files to MIDI2CV board
    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
    [midi2cv-mouser-bom.csv, midi2cv.kicad_pcb, midi2cv.kicad_sch]
2024-12-14 Added production files for the UI board
    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
    [adsr-logic.kicad_sch, filter_ui.kicad_sch, glide_ui.kicad_sch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]
2024-12-14 Fixed PSU and UI sizing bug
    [psu.kicad_pcb, psu.kicad_sch, ui-full-bom.csv]
2024-12-15 Re-added UI board BOMs
    [ui-full-bom.csv, ui-mouser-bom.csv]
2024-12-21 Added enclosure layout for top and back panels
    ref https://github.com/shmoergh/hog/issues/38
2025-01-12 Replaced VCA dual BJT footprint
    [bom.csv, core.kicad_pcb, positions.csv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]
2025-01-26 Added pico-lib
2025-03-16 Updated resistor Mouser no's and added full bom
    - Some of the THT resistors in the BOM were referencing to products with min. 1000 pcs order quantity
    - Added a full Mouser BOM which can be used to order all Mouser components by uploading to their BOM tool: https://hu.mouser.com/bom/
    [HOG-full-mouser-bom.csv, adsr-logic.kicad_sch, adsr.kicad_sch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]
